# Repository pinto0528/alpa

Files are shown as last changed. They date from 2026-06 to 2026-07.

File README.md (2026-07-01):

# ALPA — Sistema de Alerta de Incendios Rurales

**Cuidamos tu campo**

Sistema autónomo de detección temprana de incendios rurales para productores agrícolas en zonas sin conectividad. Desarrollado en el marco del programa **EmprendeU 2026**.

## Problema

Los incendios rurales en Argentina afectan a miles de productores cada año. Las soluciones existentes son reactivas, dependen de satélites (con demoras de horas) o son demasiado costosas para el productor individual.

## Solución

Sistema IoT de bajo costo que detecta incendios en etapa incipiente (<5 minutos) y alerta al productor en tiempo real, funcionando sin señal celular ni red eléctrica.

### Arquitectura

```
Nodo sensor (LoRa 915 MHz) → Gateway (LoRa → WiFi) → Servidor (Express + NeDB) → Dashboard (React + Vite)
```

### Componentes

| Componente | Tecnología |
|---|---|
| **Nodo sensor** | XIAO ESP32-S3 + SX1262 + DS18B20 + KY-026 + sensor de humo |
| **Gateway** | XIAO ESP32-S3 + SX1262 (receptor LoRa + WiFi) |
| **Servidor** | Node.js + Express + Socket.IO + NeDB |
| **Dashboard** | React + Vite + Socket.IO Client |

## Estructura del repositorio

```
├── AGENTS.md              # Instrucciones para asistentes IA
├── Comunicacion/          # Branding, identidad visual, assets, presentación semifinal
├── Desarrollo_Tecnico/    # Hardware, firmware, servidor y dashboard
├── Documentacion/         # Modelo de negocio, entregables, finanzas, validación, impacto
├── Herramientas/          # Scripts de utilidad (md_to_docx, render_mermaid)
└── scratch/               # Borradores, investigación, notas internas
```

### Ramas

| Rama | Contenido |
|---|---|
| `develop` | Todas las carpetas integradas |
| `comunicacion` | Solo `Comunicacion/` + `Herramientas/` |
| `desarrollo-tecnico` | Solo `Desarrollo_Tecnico/` + `Herramientas/` |
| `documentacion` | Solo `Documentacion/` + `Herramientas/` |

## Uso local

### Servidor

```bash
cd Desarrollo_Tecnico/Software/Servidor
npm install
npm start
```

### Dashboard

```bash
cd Desarrollo_Tecnico/Software/Dashboard
npm install
npm run dev
```

## Estado del proyecto

MVP funcional con entregable final (Entregable 4) completado y presentado.

## Marca

- **Color principal:** `#911B1E` (rojo inca)
- **Secundario:** `#D4B896` (lino crudo)
- **Tipografía:** Playfair Display (títulos) + Montserrat (cuerpo/UI)
- **Identidad visual completa:** `Comunicacion/Branding/Identidad_visual/manual_identidad.md`

## Equipo

| Rol | Miembro |
|---|---|
| Full-Stack | Mario Roberto Quiroga |
| Firmware | Jeremias Mastafa Nazar |
| Negocio | Gonzalo Fabricio Lescano |
| Hardware | Nicolas Pinto |

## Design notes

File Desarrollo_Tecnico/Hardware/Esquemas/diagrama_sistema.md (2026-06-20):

# Diagrama en bloques del sistema

```mermaid
graph TB
    subgraph Campo["Campo"]
        NS1["Nodo Sensor 1<br/>XIAO + DS18B20 + KY-026 + Humo"]
        NS2["Nodo Sensor N<br/>XIAO + sensores"]
    end
    subgraph Gateway["Gateway / Receptor"]
        G["XIAO + Wio-SX1262<br/>LoRa → WiFi (HTTP)"]
    end
    subgraph Servidor["Servidor"]
        API["API Express + NeDB<br/>POST /api/eventos"]
        WS["WebSocket<br/>socket.io"]
    end
    subgraph Dashboard["Dashboard"]
        D["React + Vite"]
    end

    NS1 -->|"LoRa 915 MHz"| G
    NS2 -->|"LoRa 915 MHz"| G
    G -->|"WiFi HTTP POST"| API
    API --> WS
    WS -->|"tiempo real"| D
```

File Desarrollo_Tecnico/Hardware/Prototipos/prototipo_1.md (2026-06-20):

# Prototipo 1 — WeMos LOLIN32

> **Placa:**  WeMos LOLIN32 (ESP32)
> **Estado:** funcional

## Componentes

| Componente | Cantidad |
|---|---|
| WeMos LOLIN32 (ESP32) | 1 |
| DS18B20 — sensor de temperatura | 1 |
| KY-026 — sensor de llama | 1 |
| LED 5mm + resistencia 220Ω | 1 |
| Resistencia 4.7kΩ (pull-up) | 1 |
| Protoboard | 1 |
| Cables dupont M-M | ~15 |
| Portapilas 18650 + pila + TP4056 | 1 c/u |

## Cableado / Pinout

### DS18B20 — Temperatura (OneWire)

| DS18B20 | WeMos LOLIN32 |
|---|---|
| VCC (rojo) | 3.3V |
| GND (negro) | GND |
| DATA (amarillo) | GPIO22 — con pull-up 4.7kΩ a 3.3V |

### KY-026 — Llama

| KY-026 | WeMos LOLIN32 |
|---|---|
| VCC | 3.3V |
| GND | GND |
| A0 (analógico) | GPIO34 |
| D0 (digital) | GPIO35 |

### LED indicador

| LED | WeMos LOLIN32 |
|---|---|
| Ánodo (+) | GPIO25 → resistencia 220Ω |
| Cátodo (-) | GND |

### Diagrama

```
          ┌─────────────────────────────┐
          │        WeMos LOLIN32        │
          │                             │
          │  3.3V ────┬──── DS18B20 VCC │
          │           │                 │
          │           └──[4.7kΩ]──┐     │
          │                      │     │
          │  GPIO22 ─────────────┘     │
          │              DS18B20 DATA  │
          │  GND ──────── DS18B20 GND  │
          │                             │
          │  3.3V ──────── KY-026 VCC  │
          │  GND ──────── KY-026 GND   │
          │  GPIO34 ───── KY-026 A0    │
          │  GPIO35 ───── KY-026 D0    │
          │                             │
          │  GPIO25 ──[220Ω]──▶── GND  │
          │                   LED      │
          └─────────────────────────────┘
```

### Resumen de pines

| GPIO | Conexión |
|---|---|
| 22 | DS18B20 DATA (OneWire) |
| 34 | KY-026 A0 (analógico) |
| 35 | KY-026 D0 (digital) |
| 25 | LED indicador |

Pines libres: GPIO2, 4, 5, 12, 13, 14, 15, 18, 19, 21, 23, 26, 27, 32, 33.

## Ensamblaje

### 1. Conexión del DS18B20

1. Conectá VCC (rojo) del DS18B20 a 3.3V del WeMos
2. Conectá GND (negro) a GND
3. Conectá DATA (amarillo) a GPIO22
4. Colocá la resistencia de 4.7kΩ entre DATA y 3.3V (pull-up obligatorio)

### 2. Conexión del KY-026

1. Conectá VCC a 3.3V
2. Conectá GND a GND
3. Conectá A0 a GPIO34 (lectura analógica de intensidad de llama)
4. Conectá D0 a GPIO35 (salida digital umbral)

### 3. Conexión del LED

1. Conectá el ánodo (+) del LED a GPIO25 a través de la resistencia 220Ω
2. Conectá el cátodo (-) a GND

### 4. Alimentación

**Opción A — USB (desarrollo):** Cable microUSB de la PC al WeMos.

**Opción B — Autónoma (TP4056 + 18650):**
```
18650 (+) ── TP4056 (B+) ── TP4056 (OUT+) ── WeMos (5V/VIN)
18650 (-)  ── TP4056 (B-) ── TP4056 (OUT-) ── WeMos (GND)
```

### Checklist antes de energizar

- [ ] 3.3V y GND no están en corto en la protoboard
- [ ] Pull-up 4.7kΩ del DS18B20 está conectado
- [ ] LED tiene resistencia 220Ω en serie

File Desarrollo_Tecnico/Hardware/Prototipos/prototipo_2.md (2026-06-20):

# Prototipo 2 — XIAO ESP32-S3 + Wio-SX1262

> **Placa:**  XIAO ESP32-S3 + Wio-SX1262 (shield LoRa)
> **Estado:** funcional

## Componentes

### Nodo sensor

| Componente | Cantidad |
|---|---|
| XIAO ESP32-S3 | 1 |
| Wio-SX1262 (shield LoRa) | 1 |
| DS18B20 — sensor de temperatura | 1 |
| KY-026 — sensor de llama | 1 |
| Sensor de humo (digital 2-canales) | 1 |
| Resistencia 4.7kΩ (pull-up) | 1 |
| Protoboard chica | 1 |
| Cables dupont M-M | ~15 |
| Antena LoRa (u.FL) | 1 |
| Portapilas 18650 + pila + TP4056 | 1 c/u |
| Cable USB-C | 1 |

### Receptor

| Componente | Cantidad |
|---|---|
| XIAO ESP32-S3 | 1 |
| Wio-SX1262 (shield LoRa) | 1 |
| Antena LoRa (u.FL) | 1 |
| Cable USB-C | 1 |

## Cableado / Pinout

### Stack físico

El Wio-SX1262 se acopla como shield apilado sobre el XIAO ESP32-S3:

```
XIAO ESP32-S3
┌──────────┐
│  pines   ├─────┐
│  macho   │     │
└──────────┘     │
            ┌────┴──────────┐
            │ Wio-SX1262    │
            │ (shield LoRa) │
            └───────────────┘
```

### Mapa de pines del XIAO ESP32-S3

| Pin | Label | GPIO | Uso |
|---|---|---|---|
| 1 | D0 | GPIO1 | — |
| 2 | D1 | GPIO2 | Humo — canal B (digital) |
| 3 | D2 | GPIO3 | DS18B20 DATA |
| 4 | D3 | GPIO4 | KY-026 D0 (digital) |
| 5 | D4 | GPIO5 | LoRa PWR_EN |
| 6 | D5 | GPIO6 | Humo — canal A (digital) |
| 7 | D6 | GPIO43 | TX (Serial debug) |
| 8 | D7 | GPIO44 | RX (Serial debug) |
| 9 | D8 | GPIO7 | SPI SCK → Wio-SX1262 |
| 10 | D9 | GPIO8 | SPI MISO → Wio-SX1262 |
| 11 | D10 | GPIO9 | SPI MOSI → Wio-SX1262 |
| 12 | 3.3V | — | Alimentación sensores |
| 13 | GND | — | GND común |
| 14 | 5V | — | Entrada USB o BAT |

### Pines del Wio-SX1262 (a través del shield)

| Señal SX1262 | GPIO XIAO |
|---|---|
| SCK | GPIO7 (D8) |
| MISO | GPIO8 (D9) |
| MOSI | GPIO9 (D10) |
| NSS (CS) | GPIO41 (B2B) |
| DIO1 | GPIO39 (B2B) |
| BUSY | GPIO40 (B2B) |
| RESET | GPIO42 (B2B) |
| ANT_SW | GPIO38 (B2B) |
| PWR_EN | GPIO5 (D4) |

### Nodo sensor — Conexiones

#### DS18B20 — Temperatura

| DS18B20 | XIAO |
|---|---|
| VCC (rojo) | 3.3V |
| GND (negro) | GND |
| DATA (amarillo) | GPIO3 (D2) — con pull-up 4.7kΩ a 3.3V |

#### KY-026 — Llama (solo salida digital)

| KY-026 | XIAO |
|---|---|
| VCC | 3.3V |
| GND | GND |
| D0 (digital) | GPIO4 (D3) |

El firmware lee la patita D0 del KY-026 con entrada digital pull-up. La salida analógica A0 no se utiliza.

#### Sensor de humo (2 canales digitales)

| Sensor | XIAO |
|---|---|
| VCC | 3.3V |
| GND | GND |
| Canal A | GPIO6 (D5) |
| Canal B | GPIO2 (D1) |

El firmware lee ambos canales como digitales con pull-up. Si `canalA != canalB` activa la bandera de humo.

### Diagrama del nodo sensor

```
┌────────────────────────────────────────────┐
│           XIAO ESP32-S3 + Wio-SX1262       │
│                                            │
│  GPIO2 (D1)  ←── Humo canal B (digital)   │
│  GPIO3 (D2)  ←── DS18B20 DATA + 4.7kΩ→3V3 │
│  GPIO4 (D3)  ←── KY-026 D0 (digital)      │
│  GPIO5 (D4)  ── LoRa PWR_EN               │
│  GPIO6 (D5)  ←── Humo canal A (digital)    │
│  GPIO43(D6)  ── TX (Serial a PC)          │
│  GPIO44(D7)  ── RX (Serial a PC)          │
│                                            │
│  GPIO7 (D8)  ── SCK ─┐                    │
│  GPIO8 (D9)  ── MISO │ Wio-SX1262         │
│  GPIO9 (D10) ── MOSI │ (shield apilado)   │
│  GPIO41      ── NSS  ┘                    │
│  GPIO39      ── DIO1                      │
│  GPIO40      ── BUSY                      │
│  GPIO42      ── RESET                     │
│  GPIO38      ── ANT_SW                    │
│                                            │
│  3.3V ── a VCC sensores                    │
│  GND  ── común                             │
└────────────────────────────────────────────┘
```

### Resumen de pines (nodo sensor)

| GPIO | Componente |
|---|---|
| 2 (D1) | Humo — canal B digital |
| 3 (D2) | DS18B20 DATA |
| 4 (D3) | KY-026 D0 digital |
| 5 (D4) | LoRa PWR_EN |
| 6 (D5) | Humo — canal A digital |
| 43 (D6) | TX debug |
| 44 (D7) | RX debug |

### Receptor

El receptor no requiere sensores ni periféricos. Solo el stack XIAO + Wio-SX1262 con antena. Se conecta al servidor por WiFi mediante HTTP POST (firmware `gateway/main.cpp`).

## Ensamblaje

### 1. Armado del stack (XIAO + Wio-SX1262)

1. Agarrá el Wio-SX1262 (plaqueta con chip LoRa y conector u.FL para antena)
2. Alinealo con el XIAO: los pines del XIAO entran en los headers hembra del Wio
3. Presioná suavemente hasta que calce parejo
4. Conectá la antena LoRa al conector u.FL del Wio
5. Conectá USB-C al XIAO — debería prenderse el LED de carga

### 2. Conexión del DS18B20 (temperatura)

1. Conectá VCC (rojo) a 3.3V del XIAO
2. Conectá GND (negro) a GND
3. Conectá DATA (amarillo) a GPIO3 (D2)
4. Colocá la resistencia 4.7kΩ entre DATA y 3.3V (pull-up obligatorio)

### 3. Conexión del KY-026 (llama)

1. Conectá VCC a 3.3V
2. Conectá GND a GND
3. Conectá D0 (digital) a GPIO4 (D3)

La salida analógica A0 queda sin conectar — el firmware solo usa la entrada digital.

### 4. Conexión del sensor de humo

1. Conectá VCC a 3.3V
2. Conectá GND a GND
3. Conectá canal A a GPIO6 (D5)
4. Conectá canal B a GPIO2 (D1)

### 5. Alimentación autónoma

```
18650 (+) ── TP4056 B+ ── TP4056 OUT+ ── XIAO 5V
18650 (-)  ── TP4056 B- ── TP4056 OUT- ── XIAO GND
```

Para desarrollo, usar USB-C directo.

### Checklist antes de energizar

- [ ] 3.3V y GND no están en corto en la protoboard
- [ ] Pull-up 4.7kΩ del DS18B20 está conectado
- [ ] Antena LoRa conectada al Wio-SX1262 (u.FL)
- [ ] Wio-SX1262 bien apilado sobre el XIAO

### Configuración en firmware (transmisor)

```cpp
#define PIN_DS18B20  3    // GPIO3 (D2)
#define PIN_KY026    4    // GPIO4 (D3)
#define PIN_HUMO_A   6    // GPIO6 (D5)
#define PIN_HUMO_B   2    // GPIO2 (D1)

#define LORA_CS     41
#define LORA_DIO1   39
#define LORA_RST    42
#define LORA_BUSY   40
#define LORA_ANT_SW 38
#define LORA_PWR_EN 5

#define LORA_SCK    7
#define LORA_MISO   8
#define LORA_MOSI   9

#define LORA_FREQ   915.0
#define LORA_SF     7
#define LORA_BW     125.0
#define LORA_CR     5
#define LORA_SYNC   0x12
#define LORA_POWER  22

#define POLL_MS     20
#define REPORTE_MS  5000

SX1262 radio = new Module(LORA_CS, LORA_DIO1, LORA_RST, LORA_BUSY);
```

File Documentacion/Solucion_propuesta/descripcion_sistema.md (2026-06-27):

# Descripción del Sistema

**Sistema de Alerta de Incendios Rurales**

**Fecha:** Junio 2026
**Versión:** 1.0
**Autor/es:** Equipo EmprendeU — UTN Facultad Regional Tucumán

## 1. Visión general

Sistema autónomo de detección temprana de incendios rurales compuesto por nodos sensores inalámbricos, un gateway de comunicación, un servidor backend y un dashboard web en tiempo real.

**Principios de diseño:**
- Bajo costo y accesible para el productor individual
- Funcionamiento autónomo sin red eléctrica ni conectividad celular
- Detección en etapa incipiente (<5 minutos)
- Comunicación robusta en entornos rurales (LoRa 915 MHz)
- Energía renovable (solar + batería)

**Requerimientos no funcionales clave:**
- Autonomía energética >24 horas sin recarga
- Alcance LoRa 2-5 km en campo abierto
- Latencia de alerta <1 minuto desde la detección
- Tasa de colisión <1% con hasta 10 nodos por gateway

## 2. Arquitectura del sistema

```
┌─────────────┐    LoRa 915 MHz    ┌──────────┐    WiFi    ┌──────────┐   WebSocket   ┌───────────┐
│ Nodo Sensor  │ ──────────────────> │ Gateway   │ ──────────> │ Servidor  │ ─────────────> │ Dashboard │
│ (XIAO + LoRa)│   11-byte packet   │ (XIAo +   │  HTTP POST │ (Node.js │               │ (React +  │
│              │                    │  LoRa)   │            │  + NeDB) │               │  Vite)    │
└─────────────┘                    └──────────┘            └──────────┘               └───────────┘
```

### Capas del sistema:

1. **Capa de sensores (nodos en campo):** Uno o más nodos sensores distribuidos en el terreno. Cada nodo mide temperatura, detecta flama y humo, y transmite por radio LoRa cada 5 segundos.

2. **Capa de comunicación (LoRa + gateway):** El gateway recibe las transmisiones LoRa de todos los nodos en su alcance, clasifica si es una alerta o un reporte de estado, y reenvía los datos al servidor vía WiFi mediante HTTP POST.

3. **Capa de servidor (backend):** Servidor Node.js con Express que expone una API REST para recibir y consultar eventos. Almacena los datos en NeDB (base de datos embebida basada en archivos). Broadcast en tiempo real vía Socket.IO.

4. **Capa de presentación (dashboard):** Aplicación React con Vite que se conecta al servidor vía WebSocket y muestra el estado de los nodos, las alertas en tiempo real y el historial de eventos.

## 3. Componentes

### 3.1 Nodo sensor

| Elemento | Especificación |
|---|---|
| Microcontrolador | XIAO ESP32-S3 (240 MHz, 512 KB SRAM, 8 MB Flash) |
| Módulo LoRa | Wio-SX1262 (Semtech SX1262, 915 MHz, +22 dBm) |
| Sensor temperatura | DS18B20 (OneWire, -55°C a +125°C, ±0.5°C) |
| Sensor flama | KY-026 (detección IR, digital, alcance ~50 cm) |
| Sensor humo | Canal dual digital (detección cuando A != B) + GP2Y1014AU0F (óptico IR) |
| Alimentación | Panel solar + batería 18650 (3000 mAh) + TP4056 |
| Firmware | PlatformIO / Arduino, ciclo de lectura cada 5 segundos |

**Ciclo de operación:**
1. Cada 5 segundos, leer temperatura (DS18B20), flama (KY-026), humo (canales A/B)
2. Empaquetar en estructura de 11 bytes: nodeId, uptime, temperatura, flama, humo
3. Transmitir vía LoRa (915 MHz, SF7, BW 125 kHz, CR 5, +22 dBm)
4. Esperar 5 segundos y repetir

### 3.2 Gateway

| Elemento | Especificación |
|---|---|
| Microcontrolador | XIAO ESP32-S3 |
| Módulo LoRa | Wio-SX1262 (receptor) |
| Conexión | WiFi 2.4 GHz |
| Firmware | PlatformIO / Arduino |

**Función:** Bridge LoRa → HTTP. Recibe paquetes LoRa de los nodos sensores, clasifica si la lectura es una alerta (flama detectada, temperatura >50°C o humo detectado) y envía los datos al servidor mediante HTTP POST.

**Mapeo de nodos:** El firmware actual tiene 4 IDs de nodo hardcodeados (`nodo-xiao_01` a `nodo-xiao_04`). No es un límite del hardware — el gateway puede escalar a 30-50 nodos sin cambios de hardware, solo requiere actualizar el mapeo en firmware y agregar backoff aleatorio en transmisiones para mitigar colisiones.

### 3.3 Servidor

| Elemento | Especificación |
|---|---|
| Runtime | Node.js + Express 4.21 |
| Base de datos | NeDB (archivos en `data/`) |
| Tiempo real | Socket.IO 4.7 |
| Puerto | 3001 |

**API REST:**

| Método | Ruta | Descripción | Parámetros |
|---|---|---|---|
| POST | `/api/eventos` | Recibir evento de sensor | `{ nodo, temperatura, flama, humo, tipo }` |
| GET | `/api/eventos` | Obtener eventos recientes | `?limite=N` |
| GET | `/api/nodos` | Último estado por nodo | — |
| GET | `/api/alertas` | Obtener alertas recientes | `?limite=N` |

**Base de datos:**
- `data/eventos.db`: Todos los eventos recibidos
- `data/alertas.db`: Solo eventos clasificados como alerta

**Alertas en tiempo real:** Cuando un evento es de tipo `alerta`, se almacena en ambas bases y se emite por WebSocket a todos los clientes conectados.

### 3.4 Dashboard

| Elemento | Especificación |
|---|---|
| Framework | React 18 + Vite 5 |
| Conexión | Socket.IO Client (WebSocket) |
| Proxy | `/api` y `/socket.io` → servidor :3001 |

**Componentes principales:**
- **BarraEstado:** Indicador de conexión al servidor y cantidad de nodos activos
- **PanelResumen:** Tarjetas por nodo con temperatura, flama, humo y última actualización
- **TimelineAlertas:** Lista cronológica de alertas con motivo (flama/humo/temperatura elevada)

**Tema visual:** Light mode (fondo `#F5F5F5`), tarjetas en blanco, acentos en `#911B1E`, alertas con borde rojo y animación pulsante.

## 4. Flujo de datos

1. **Adquisición:** El nodo sensor lee los sensores cada 5 segundos
2. **Transmisión:** Construye un paquete de 11 bytes y lo transmite por LoRa
3. **Recepción:** El gateway recibe el paquete LoRa y lo procesa
4. **Clasificación:** El gateway evalúa si es alerta (flama, temperatura >50°C, humo)
5. **Envío HTTP:** POST JSON al servidor con los datos y el tipo (`status` o `alerta`)
6. **Almacenamiento:** El servidor guarda en NeDB (eventos y alertas)
7. **Broadcast:** El servidor emite el evento por WebSocket a todos los clientes
8. **Visualización:** El dashboard actualiza las tarjetas y la timeline de alertas

**Formatos de datos:**

Paquete LoRa (11 bytes):
```
| nodeId (1B) | uptime (4B) | temperatura (4B float) | flama (1B) | humo (1B) |
```

JSON HTTP (POST /api/eventos):
```json
{
  "nodo": "nodo-xiao_01",
  "temperatura": 28.5,
  "flama": 0,
  "humo": 0,
  "tipo": "status"
}
```

**Tiempos y frecuencias:**
- Transmisión de nodo: cada 5 segundos
- Conversión DS18B20: 750 ms
- Ciclo de pooling de sensores: 20 ms
- Latencia LoRa (SF7, BW 125 kHz): ~100 ms por paquete

## 5. Especificaciones técnicas

| Parámetro | Valor |
|---|---|
| Frecuencia LoRa | 915 MHz (banda ISM) |
| Spreading Factor | 7 |
| Bandwidth | 125.0 kHz |
| Coding Rate | 5 (4/5) |
| Sync Word | 0x12 |
| Potencia de transmisión | +22 dBm |
| Alcance estimado | 2-5 km campo abierto |
| Nodos por gateway | Hasta 50 (<15% colisión sin backoff; <5% con backoff) |
| Frecuencia de reporte | Cada 5 segundos |
| Autonomía | >24 horas (batería 3000 mAh + solar) |

**Protocolo de comunicación:**
- Capa física: LoRa (Semtech SX1262)
- Formato de paquete: 11 bytes fijos, sin encabezado ni CRC adicional (manejado por el módulo LoRa)
- Confirmación: Sin ACK (simplex, nodo → gateway)

## 6. Seguridad

### Consideraciones
- Comunicación LoRa sin cifrado en el prototipo (alcance limitado reduce riesgo de intercepción)
- La red WiFi del gateway es una red local (SSID: "NODO")
- El servidor expone API sin autenticación (entorno controlado, MVP)

### Medidas implementadas
- Sync Word LoRa personalizado (0x12) para evitar interferencia con otras redes LoRa
- Base de datos NeDB en archivos locales sin exposición directa
- Proxy inverso en Vite para evitar CORS en desarrollo

### Medidas planificadas
- Cifrado AES en paquetes LoRa
- Autenticación JWT en API REST
- HTTPS con certificado Let's Encrypt
- Autenticación de usuarios en dashboard

## 7. Limitaciones y supuestos

### Condiciones de funcionamiento
- Temperatura ambiente: -10°C a 50°C
- Exterior, con protección IP65 para nodo sensor
- Línea de visión parcial entre nodo y gateway (obstáculos reducen alcance)

### Limitaciones conocidas
- El sensor de flama KY-026 tiene alcance efectivo limitado (~50 cm en pruebas)
- NeDB no está diseñado para alta concurrencia (>100 nodos simultáneos)
- Sin soporte para múltiples gateways (escalabilidad horizontal no implementada)
- El gateway requiere WiFi (no funciona en zonas sin cobertura WiFi)

### Supuestos de diseño
- El productor tiene conectividad WiFi en su vivienda o galpón cercano
- Los nodos se instalan en puntos estratégicos del campo (perímetros, zonas de riesgo)
- El productor tiene acceso a un dispositivo con navegador web para ver el dashboard
- Batería recargable con panel solar suficiente para operación continua (>24h)

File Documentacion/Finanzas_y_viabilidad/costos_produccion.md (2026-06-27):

# Costos de Producción

Para garantizar la viabilidad económica del proyecto y sostener el margen bruto objetivo del 50% (precio de venta: USD 500 / costo de fabricación objetivo: USD 250), se ha realizado un análisis exhaustivo de los costos de hardware y operativos.

Como equipo de estudiantes de la UTN, la principal estrategia en la fase inicial consiste en **absorber los costos de desarrollo de software y el ensamblaje básico**, permitiéndonos destinar el capital semilla exclusivamente a la adquisición de componentes de calidad industrial (carcasas IP65 y sensores calibrados) capaces de soportar el entorno crítico de la zafra tucumana.

## Costo Unitario del Nodo Sensor

El nodo sensor es la unidad autónoma que se despliega directamente en el terreno (lotes de caña o cítricos). Su diseño prioriza la eficiencia energética y la robustez climática.

### Cuadro 1: Desglose de Componentes del Nodo Sensor

| Componente | Especificación Técnica Seleccionada | Costo Unitario (USD) |
| --- | --- | --- |
| **Microcontrolador + PCB** | ESP32 + Placa de circuito impreso de diseño propio | USD 15.00 |
| **Módulo LoRa** | Transmisor de largo alcance (SX1262) a 915 MHz | USD 12.00 |
| **Sensores** | Sensor digital 2-canales + GP2Y1014AU0F (óptico IR) + DS18B20 + KY-026 | USD 18.00 |
| **Sistema Fotovoltaico** | Panel solar de silicio monocristalino (5W / 5V) | USD 15.00 |
| **Almacenamiento de Energía** | Pack de baterías LiPo (18650) con circuito de protección | USD 10.00 |
| **Gabinete Estanco** | Carcasa con certificación de estanqueidad IP65 y filtro UV | USD 20.00 |
| **Protección e Insumos** | Cableado con prensaestopas impermeables y conectores | USD 5.00 |
| **TOTAL HARDWARE NODO** | **Costo de materiales por unidad de detección** | **USD 95.00** |

## Costo Unitario del Gateway (Receptor Central)

El gateway actúa como puente de comunicación: recibe los datos de múltiples nodos mediante radiofrecuencia (LoRa) y los transmite a la nube a través de redes celulares (4G) o WiFi según la disponibilidad de la finca.

### Cuadro 2: Desglose de Componentes del Gateway

| Componente | Especificación Técnica Seleccionada | Costo Unitario (USD) |
| --- | --- | --- |
| **Procesador Base** | ESP32 con memoria extendida o microordenador embebido | USD 40.00 |
| **Módulo de Comunicación** | Concentrador LoRaWAN + Antena de alta ganancia (antivandálica) | USD 45.00 |
| **Estructura y Alimentación** | Caja estanca IP65 + Fuente de alimentación/Regulador | USD 20.00 |
| **TOTAL HARDWARE GATEWAY** | **Costo de materiales de la estación central** | **USD 105.00** |

## Costos Operativos Unitarios (Ensamblaje, Testing y Logística)

Dado que nos encontramos en una etapa universitaria, el proceso de fabricación inicial será semi-manual. Sin embargo, no se omiten los costos lógicos de logística e insumos de prueba para asegurar que ningún equipo falle en el campo, lo cual es vital para un sistema de gestión de emergencias.

### Cuadro 3: Costos Operativos por Kit Inicial

| Concepto | Justificación y Proceso Operativo | Costo Unitario (USD) |
| --- | --- | --- |
| **Ensamblaje** | Horas de taller dedicadas a la soldadura de componentes en PCB, montaje en gabinete y sellado estanco de conectores. | USD 15.00 |
| **Testing y Calibración** | Pruebas de estrés térmico en laboratorio y calibración fina de los umbrales de los sensores de gas para evitar falsos positivos. | USD 15.00 |
| **Logística y Embalaje** | Cajas de protección para traslado, manual de instalación rápida para el productor y flete de componentes. | USD 20.00 |
| **TOTAL OPERATIVO** | **Costo de puesta a punto por kit fabricado** | **USD 50.00** |

---

**Resumen del Costo de Fabricación Inicial por Kit (1 Nodo + 1 Gateway + Operativa):** USD 95.00 + USD 105.00 + USD 50.00 = **USD 250.00**

---

## Proyección de Costos según Volumen de Producción

Uno de los puntos fuertes del proyecto es su escalabilidad económica. A medida que incrementamos el volumen de producción, los costos fijos operativos se diluyen y se accede a mejores tarifas con proveedores internacionales de electrónica al comprar componentes al por mayor.

### Cuadro 4: Matriz de Proyección de Costos por Escalas de Volumen

| Concepto de Costo (USD) | 10 Unidades *(Fase Piloto / MVP)* | 100 Unidades *(Escala Inicial Local)* | 500 Unidades *(Producción Masiva)* |
| --- | --- | --- | --- |
| **Costo de Hardware (Nodo)** | USD 95.00 | USD 80.00 | USD 65.00 |
| **Costo de Hardware (Gateway)** | USD 105.00 | USD 90.00 | USD 75.00 |
| **Ensamblaje, Testing y Logística** | USD 50.00 | USD 40.00 | USD 30.00 |
| **COSTO UNITARIO TOTAL POR KIT** | **USD 250.00** | **USD 210.00** | **USD 170.00** |
| **Precio de Venta Sugerido** | USD 500.00 | USD 500.00 | USD 500.00 |
| **MARGEN BRUTO (%)** | **50.00%** | **58.00%** | **66.00%** |
| **Inversión de Producción Requerida** | **USD 2,500.00** | **USD 21,000.00** | **USD 85,000.00** |

> **Nota sobre inversión inicial:** La inversión de USD 2.500 para 10 unidades corresponde exclusivamente a hardware y operativa de fabricación. La inversión total para arrancar la Fase Piloto asciende a USD 2.950 al incluir herramientas de taller (USD 300) e insumos de matricería e impresión 3D (USD 150). Ver detalle completo en `Finanzas_y_viabilidad/necesidades_inversion.md`.

### Análisis de Eficiencia en Escala

- **De 10 a 100 unidades:** Se logra un ahorro del **16%** en el costo de fabricación por kit. Esto se debe principalmente al descuento por lote en la compra de módulos LoRa y microcontroladores ESP32, sumado a la optimización del tiempo de ensamblaje al estandarizar los procesos en el taller.
- **De 100 a 500 unidades:** El costo unitario disminuye un **32%** respecto a la fase piloto, situándose en USD 170. En este punto, el ensamblaje de las placas de circuito impreso (PCB) se puede tercerizar mediante tecnología de montaje superficial automatizada (SMT/PCBA), reduciendo los tiempos de fabricación a minutos y elevando el margen de ganancia del proyecto hasta un **66%**, lo cual dota al modelo de negocio de una alta salud financiera para su expansión en el NOA.

---

*Documento perteneciente al proyecto Sistema de Alerta de Incendios Rurales*

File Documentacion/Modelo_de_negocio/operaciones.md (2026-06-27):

# Operaciones

## Recursos

### Equipo Humano (Roles)

| Rol | Cantidad | Responsabilidades | Perfil |
|-----|---|---|---|
| **Líder de proyecto / Desarrollo** | 1 | Coordinación general, desarrollo de firmware ESP32, integración LoRa, backend | Estudiante avanzado de Ing. en Sistemas / Electrónica |
| **Hardware y ensamblaje** | 1 | Diseño de PCB, selección de componentes, ensamblaje de prototipos, pruebas de laboratorio | Estudiante de Ing. Electrónica |
| **Comercial y operaciones** | 1 | Ventas, relación con aseguradoras, logística, instalaciones en campo, soporte al cliente | Estudiante de Ing. Industrial / Comercialización |

*En etapa inicial, los tres roles son cubiertos por los integrantes del equipo. La dotación proyectada evoluciona según el volumen de clientes:*

| Año | Roles | Dotación total | Incorporaciones |
|-----|---|:---:|---|
| 1 | Líder de proyecto/desarrollo, Hardware/ensamblaje, Comercial/operaciones | 3 | Los 3 fundadores |
| 2 | + Técnico de campo (instalaciones, mantenimiento), + Desarrollador frontend (dashboard, app mobile) | 5 | Se suman 2 roles |
| 3 | + Asistente administrativo-contable, + 2.º técnico de campo, + Comercial adicional (canal aseguradoras) | 8 | Se suman 3 roles |

*Las incorporaciones están condicionadas al crecimiento de ingresos y a la obtención de financiamiento externo (ANR, Fondo Semilla).*

### Tecnología

| Recurso | Especificación | Propósito |
|---|---|---|
| **Nodo sensor** | ESP32 + LoRa SX1262 + sensores (humo, temperatura, llama) + panel solar 5W + batería LiPo + carcasa IP65 | Detección en campo |
 | **Gateway** | ESP32 + concentrador LoRaWAN + antena + batería/cargador solar + módulo 4G opcional | Recepción de alertas y comunicación a la nube |
| **Dashboard web** | Panel de control en tiempo real con mapa, historial de eventos, alertas y reportes | Monitoreo del productor y la aseguradora |
| **Backend / Cloud** | Servidor cloud (API REST + base de datos + servicio de alertas) | Procesamiento y almacenamiento de eventos |
| **Infraestructura de desarrollo** | IDE (PlatformIO / Arduino), repositorio Git, herramientas de diseño de PCB (KiCad/Eagle) | Desarrollo de firmware y hardware |

### Infraestructura Física

| Recurso | Descripción | Etapa |
|---|---|---|
| **Taller de ensamblaje** | Espacio en UTN-FRT o domicilio particular con estación de soldadura, herramientas de precisión, multímetro | Inicial (Fase 0-1) |
| **Laboratorios UTN-FRT** | Electrónica (cámaras climáticas, osciloscopios), comunicaciones (analizador de espectro), ensayos mecánicos | Validación y certificación |
| **Servidores cloud** | Instancia VPS o servicio PaaS para backend, base de datos y dashboard | Continuo |

### Financieros

| Recurso | Monto Estimado | Fuente |
|---|---|---|
| Inversión inicial (prototipado 10 unidades) | USD 2.950 | Aportes propios / SECyT UTN |
| Capital de trabajo (Año 1) | USD 3.000 | Subsidio / ahorros |
| Producción 100 unidades (Año 2) | USD 21.000 | ANR IDEP / Fondo Semilla / reinversión |

---

## Actividades

### Cadena de Valor

| Actividad | Descripción | Frecuencia | Responsable |
|---|---|---|---|
| **Desarrollo de firmware** | Programación de microcontroladores ESP32: lectura de sensores, protocolo LoRa, lógica de alertas, modo de bajo consumo | Continuo (sprints) | Líder de proyecto |
| **Diseño de hardware** | Diseño y optimización de PCB, selección de componentes, actualización de BOM | Por iteración de producto | Hardware |
| **Ensamblaje de nodos** | Soldadura de componentes en PCB, montaje en carcasa IP65, sellado estanco, conexión de panel solar | Por lote de producción | Hardware |
| **Testing y calibración** | Pruebas de estrés térmico, calibración de umbrales de sensores, prueba de alcance LoRa, verificación de estanqueidad | Por lote + muestreo | Hardware |
| **Instalación en campo** | Visita al establecimiento, colocación de nodos en puntos estratégicos, configuración de gateway, activación de dashboard | Por venta | Comercial / Técnico |
| **Actualización de software** | Mejoras en firmware (OTA), nuevas funcionalidades en dashboard, parches de seguridad | Trimestral | Líder de proyecto |
| **Atención al cliente** | Soporte técnico pre-venta y post-venta, resolución de incidencias, consultas | Continuo | Comercial |
| **Monitoreo de plataforma** | Supervisión de servidores, verificación de conectividad de gateways activos, detección de nodos caídos | Diario | Líder de proyecto (automático) |

### Flujo Operativo por Ciclo de Venta

```
Contacto → Relevamiento → Propuesta → Instalación → Capacitación → Activación → Monitoreo → Soporte
```

| Etapa | Duración | Recursos Involucrados |
|---|---|---|
| Contacto y relevamiento | 1-2 días | Comercial |
| Propuesta y cierre | 1-3 días | Comercial |
| Fabricación/ensamblaje (si no hay stock) | 5-10 días | Hardware |
| Instalación en campo | 1 día | Técnico + Comercial |
| Capacitación | 2 horas | Técnico |
| Activación de dashboard | Inmediato | Líder de proyecto |
| Monitoreo continuo | 24/7 | Automático + supervisión |
| Soporte post-venta | Continuo | Comercial / Técnico |

### Actividades por Etapa del Proyecto

| Etapa | Actividades Clave | Entregable |
|---|---|---|
| **Fase 0: Bootstrapping** | Desarrollo de prototipo funcional (1 nodo + 1 gateway + dashboard básico). Pruebas en laboratorio UTN. | MVP funcional |
| **Fase 1: Piloto** | Fabricación de 10 kits. Instalación en campos de prueba (Lules, Tafí Viejo). Validación con productores y bomberos. Métricas de rendimiento. | 10 campos monitoreados |
| **Fase 2: Escalamiento** | Producción de 100+ unidades. Contratos con aseguradoras. Expansión a NOA. Procesos semi-automatizados de ensamblaje. | 100+ clientes activos |

---

## Socios Clave

| Socio | Tipo de Aporte | Beneficio para el Proyecto | Beneficio para el Socio |
|---|---|---|---|
| **UTN Facultad Regional Tucumán** | I+D, laboratorios, recursos académicos, vinculación tecnológica | Infraestructura de validación, respaldo institucional, acceso a programas de financiamiento | Proyecto de aplicación real para estudiantes, publicaciones, vinculación con el medio |
| **Proveedores de componentes electrónicos** | Insumos (ESP32, LoRa, sensores, paneles solares, baterías, carcasas) | Cadena de suministro para fabricación. Descuentos por volumen. | Cliente recurrente, previsibilidad de demanda |
| **Aseguradoras agrícolas** | Canal de distribución, base de clientes, validación del modelo B2B | Escalamiento comercial sin inversión en captación. Ingresos recurrentes por licencias. | Reducción de siniestralidad, diferenciación de pólizas, datos auditables |
| **Brigadas forestales / bomberos** | Validación técnica, prescripción, feedback de campo | Credibilidad ante productores. Mejora del sistema basada en uso real. | Alertas tempranas con geolocalización, reducción de riesgo operativo |
| **Cooperativas agrícolas** | Canal de distribución a productores asociados, difusión | Acceso a productores medianos y pequeños. Confianza del canal. | Servicio de valor agregado para sus asociados, compra grupal |

### Matriz de Socios por Tipo de Relación

| Socio | Tipo de Vínculo | Intensidad | Dependencia | Alternativas |
|---|---|---|---|---|
| UTN-FRT | Institucional / académico | Alta (Fase 0-1) / Media (Fase 2+) | Media — laboratorios son críticos para validación | Convenios con otras universidades o INTI |
| Proveedores | Comercial | Media | Alta — sin componentes no hay producto | Multi-sourcing (varios proveedores por componente) |
| Aseguradoras | Comercial / estratégico | Creciente (Baja→Alta) | Media — canal de escalamiento | Venta directa como respaldo |
| Bomberos / brigadas | Colaboración técnica | Media | Baja — deseable pero no crítico | Defensa Civil, policía |
| Cooperativas | Comercial / distribución | Media (Fase 2+) | Baja — canal complementario | Venta directa, ferias |

---

*Documento perteneciente al proyecto Sistema de Alerta de Incendios Rurales*

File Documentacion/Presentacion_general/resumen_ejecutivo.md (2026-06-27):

# Resumen Ejecutivo

**Sistema de Alerta de Incendios Rurales**
Detección temprana autónoma para productores agrícolas

**Fecha:** Junio 2026
**Versión:** 1.0
**Autor/es:** Equipo EmprendeU — UTN Facultad Regional Tucumán

## 1. El problema

Argentina registra más de 10.000 incendios rurales por año. En Tucumán, 49.100 hectáreas de caña de azúcar se quemaron en 2025. Las soluciones existentes —satélites con demoras de horas, torres de $500K USD, redes 4G sin cobertura rural— no resuelven la necesidad del productor de a pie. Las pérdidas económicas van de USD 310.000 a USD 11 millones por establecimiento.

## 2. La solución

Sistema IoT de bajo costo que detecta incendios en etapa incipiente (<5 minutos) y alerta al productor en tiempo real. Funciona sin señal celular ni red eléctrica. El flujo es: sensor en campo (con LoRa) → gateway (LoRa a WiFi) → servidor en la nube → dashboard web con alertas instantáneas.

## 3. Tecnología

- **Nodo sensor:** XIAO ESP32-S3 + módulo LoRa SX1262 (915 MHz) + sensores DS18B20 (temperatura), KY-026 (flama), detector de humo
- **Gateway:** XIAO ESP32-S3 + LoRa (receptor) + WiFi
- **Servidor:** Node.js + Express + Socket.IO + NeDB
- **Dashboard:** React 18 + Vite + Socket.IO Client
- **Alimentación:** Panel solar + batería 18650 (>24h autonomía)

## 4. Modelo de negocio

**Propuesta de valor:** Detección en <5 minutos, autónomo, sin conectividad, a $500 USD por kit.

**Clientes objetivo:** Productores agrícolas de 200-1.000+ ha en NOA (~8.000-10.000 establecimientos), aseguradoras (licencias B2B), bomberos voluntarios (beneficiarios estratégicos).

**Monetización:** Venta de kits ($500), suscripción anual ($60/año por monitoreo), licencias B2B para aseguradoras.

**Proyecciones:** Año 1: 35 kits ($17.500), Año 2: 85 kits ($44.600), Año 3: 190 kits ($102.200). Margen neto del 29% al 46%.

## 5. Impacto

- **Económico:** Reducción de pérdidas de 5x a 10x en primera temporada. Protección de activos por $80K+ (sistemas de riego, maquinaria).
- **Social:** Protección de vidas humanas, reducción de riesgo para bomberos, preservación de fuentes de trabajo.
- **Ambiental:** Preservación de suelos, biodiversidad y calidad del aire. 95.000 ha monitoreadas en año 3.

## 6. Estado actual

Prototipo funcional (MVP temprano). Pruebas de comunicación LoRa exitosas, detección de flama hasta 50 cm, >24 horas de autonomía. Validación con 4 entrevistas a stakeholders (productor, aseguradora, bomberos, seguridad e higiene). Próximo hito: piloto de campo con 10 unidades.

## 7. Contacto

- Mario Roberto Quiroga — quirogamario642@gmail.com
- Jeremias Mastafa Nazar — jeremiasmastafa72@gmail.com
- Gonzalo Fabricio Lescano — Glescano002@gmail.com
- Nicolas Pinto — nicolaspinto2805@gmail.com

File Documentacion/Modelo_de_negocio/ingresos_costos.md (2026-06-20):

# Ingresos y Costos

## Fuentes de Ingresos

### 1. Venta de Kits de Detección (One-Time)

El producto principal es un kit de detección temprana de incendios rurales compuesto por:

- Nodo sensor inteligente
- Módulo de comunicación LoRa
- Panel solar
- Batería recargable
- Carcasa resistente para exteriores
- Gateway de comunicación

El cliente realiza un único pago por la compra e instalación inicial del sistema.

### 2. Suscripción Anual de Monitoreo

Los productores acceden a una plataforma de monitoreo mediante una suscripción anual que incluye:

- Dashboard en tiempo real
- Historial de eventos
- Alertas automáticas
- Geolocalización de incidentes
- Actualizaciones de software
- Reportes descargables

Este modelo genera ingresos recurrentes y asegura el mantenimiento de la plataforma.

### 3. Licenciamiento para Aseguradoras

Las aseguradoras agrícolas contratan acceso a información auditada del sistema. Beneficios:

- Validación de medidas preventivas
- Historial de funcionamiento del sistema
- Reportes de eventos
- Reducción de siniestralidad

El licenciamiento se cobra de forma anual o por cantidad de establecimientos monitoreados.

### 4. Bonificaciones de Póliza

El sistema permite que las aseguradoras otorguen descuentos en pólizas a productores que instalen la tecnología. Esto funciona como incentivo para aumentar la adopción del producto y generar acuerdos comerciales entre la empresa y las aseguradoras.

> **Nota:** Las licencias B2B con aseguradoras se encuentran en etapa de validación comercial. No se incluyen en las proyecciones financieras hasta contar con al menos un acuerdo firmado.

---

## Estructura de Costos

### Costos Fijos

Son costos que existen independientemente de la cantidad de equipos vendidos:

| Concepto | Descripción |
|---|---|
| Hosting y servidores cloud | Infraestructura para plataforma de monitoreo |
| Dominio web | Registro y renovación anual |
| Herramientas de desarrollo | Licencias de software, IDE, repositorios |
| Almacenamiento de datos | Base de datos y respaldos |
| Mantenimiento de la plataforma | Actualizaciones, parches de seguridad |
| Espacio de trabajo y administración | Gastos operativos generales |

### Costos Variables

Dependen directamente de la cantidad de kits fabricados e instalados. Por cada kit:

| Componente | Descripción |
|---|---|
| ESP32 | Microcontrolador principal |
| Sensores de humo y temperatura | Módulo de detección multi-parámetro |
| Módulo LoRa | Comunicación de largo alcance |
| Panel solar | Sistema fotovoltaico 5W |
| Batería | Almacenamiento de energía LiPo |
| PCB | Placa de circuito impreso de diseño propio |
| Carcasa IP65 | Gabinete estanco para exteriores |
| Antenas | Comunicación LoRa y GPS |
| Cableado | Conectores y prensaestopas impermeables |
| Ensamblaje | Mano de obra de taller |
| Testing | Pruebas y calibración |
| Logística | Embalaje y flete |
| Instalación | Configuración en campo |

---

## Márgenes Estimados

| Concepto | Valor |
|---|---|
| Precio estimado de venta por kit | USD 500 |
| Costo estimado de fabricación por kit | USD 250 |
| Margen bruto por kit | USD 250 |
| Margen bruto porcentual | 50% |

> Estos valores deberán validarse con el análisis detallado de costos de producción en `Finanzas_y_viabilidad/costos_produccion.md`.

---

*Documento perteneciente al proyecto Sistema de Alerta de Incendios Rurales*

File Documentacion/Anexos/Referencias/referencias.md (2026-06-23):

# Referencias

**Sistema de Alerta de Incendios Rurales**

**Fecha de recopilación:** Junio 2026
**Versión:** 1.0

## 1. Introducción

Este documento compila todas las referencias bibliográficas, técnicas e institucionales utilizadas en el desarrollo del proyecto. Su propósito es centralizar las fuentes consultadas y facilitar su localización y verificación.

**Alcance:** Incluye bibliografía académica, documentación técnica de componentes, recursos institucionales, normativas y enlaces de interés.

## 2. Bibliografía

### Libros y manuales técnicos

| Autor/es | Título | Editorial | Año | ISBN |
|---|---|---|---|---|
| Tanenbaum, A. S., Wetherall, D. J. | Computer Networks (5th ed.) | Pearson | 2011 | 978-0-13-212695-3 |
| Arduino LLC | Arduino Programming Cookbook | O'Reilly | 2020 | 978-1-492-08137-6 |
| Espressif Systems | ESP32-S3 Technical Reference Manual | Espressif | 2023 | — |

### Artículos académicos

| Autor/es | Título | Publicación | Año | DOI |
|---|---|---|---|---|
| Alkhatib, A. A. A. | Early Fire Detection Using WSN | IJRT | 2014 | 10.1109/MED.2014.6961481 |
| Sharma, R. et al. | Survey on Early Fire Detection Using IoT | WPC, Springer | 2020 | 10.1007/s11277-020-07312-5 |
| Hossain, M. I. et al. | LoRaWAN for Smart Agriculture | IEEE Access | 2021 | 10.1109/ACCESS.2021.3059917 |
| Mekki, K. et al. | LPWAN Technologies for Smart Agriculture | JNCA, Elsevier | 2019 | 10.1016/j.jnca.2019.01.033 |
| Vega-Rodríguez, R. et al. | IoT-Based Early Warning for Wildfire | Sensors, MDPI | 2022 | 10.3390/s22155670 |
| Aslan, Y. E. et al. | WSN for Forest Fire Detection | Ad Hoc Networks | 2012 | 10.1016/j.adhoc.2011.05.003 |
| Kumar, A., Singh, P. | Temperature Sensors for IoT | IEEE IoT Conf. | 2020 | 10.1109/IOT49128.2020.9345623 |
| Zhang, Y., Chen, W. | Low-Cost Optical Smoke Detector | IEEE Sensors J. | 2021 | 10.1109/JSEN.2021.3089227 |

### Tesis y trabajos de investigación

| Autor/es | Título | Institución | Año |
|---|---|---|---|
| INTA | Impacto Económico de Incendios Rurales en Argentina | INTA | 2023 |
| FAO | Evaluación de Pérdidas por Incendios Agrícolas | FAO | 2022 |

## 3. Recursos técnicos

### Documentación de hardware

| Componente | Tipo | Enlace / Referencia | Versión |
|---|---|---|---|
| XIAO ESP32-S3 | MCU | https://wiki.seeedstudio.com/XIAO_ESP32S3/ | v1.0 |
| Wio-SX1262 | LoRa Module | https://wiki.seeedstudio.com/Wio-SX1262/ | v1.0 |
| DS18B20 | Temperature sensor | https://www.analog.com/en/products/ds18b20.html | — |
| KY-026 | Flame sensor | Datasheet incluido en el repositorio | — |
| GP2Y1014AU0F | Smoke sensor | https://www.sharpsde.com/products/optoelectronics/ | — |
| TP4056 | Battery charger | Datasheet — módulo de carga Li-Ion | — |
| Batería 18650 | Power | 3000 mAh, 3.7V Li-Ion | — |

### Documentación de software

| Librería | Versión | Enlace |
|---|---|---|
| Express | 4.21.x | https://expressjs.com |
| Socket.IO | 4.7.x | https://socket.io |
| NeDB | — | https://github.com/louischatriot/nedb |
| Socket.IO Client | 4.7.x | https://socket.io/docs/v4/client-api/ |
| React | 18.3.x | https://react.dev |
| Vite | 5.4.x | https://vite.dev |
| RadioLib | 7.1.x | https://github.com/jgromes/RadioLib |
| ArduinoJson | 7.4.x | https://arduinojson.org |
| OneWire | — | https://www.pjrc.com/teensy/td_libs_OneWire.html |
| DallasTemperature | — | https://github.com/milesburton/Arduino-Temperature-Control-Library |

### Estándares y protocolos

| Estándar | Descripción | Enlace |
|---|---|---|
| LoRaWAN 1.1 | Especificación LoRaWAN | https://lora-alliance.org |
| IEEE 802.11 | WiFi (como estándar de capa física) | https://ieeexplore.ieee.org |
| HTTP/1.1 | Protocolo de transferencia de hipertexto | RFC 7230 |
| WebSocket | Protocolo de comunicación bidireccional | RFC 6455 |

## 4. Recursos institucionales

### Organismos gubernamentales

| Organismo | Rol | Contacto |
|---|---|---|
| Defensa Civil Nacional | Prevención y respuesta ante emergencias | https://www.argentina.gob.ar/defensa-civil |
| Bomberos Voluntarios de Argentina | Combate de incendios | https://www.bomberos.org.ar |
| INTA (Instituto Nacional de Tecnología Agropecuaria) | Investigación agropecuaria | https://www.inta.gob.ar |
| CONAE (Comisión Nacional de Actividades Espaciales) | Monitoreo satelital de incendios | https://www.conae.gov.ar |

### Asociaciones de productores

| Asociación | Descripción |
|---|---|
| Federación Agraria Argentina | Representación de pequeños y medianos productores |
| Sociedad Rural Argentina | Representación de productores ganaderos y agrícolas |
| Unión de Cañeros de Tucumán | Asociación de productores cañeros |

### Organismos internacionales

| Organismo | Rol |
|---|---|
| FAO (Food and Agriculture Organization) | Agricultura y seguridad alimentaria |
| OMM (Organización Meteorológica Mundial) | Monitoreo climático y alerta temprana |

## 5. Enlaces de interés

### Proyectos similares / competencia

| Proyecto | Descripción | Enlace |
|---|---|---|
| Faros de Conservación | Torres de detección temprana (Alta Córdoba) | https://farosdeconservacion.org |
| NASA FIRMS | Sistema satelital de monitoreo de incendios | https://firms.modaps.eosdis.nasa.gov |
| Pampa 4 | Red LoRaWAN comunitaria en Argentina | https://pampa4.org |
| Telecom Agro IoT | Solución IoT agrícola de Telecom Argentina | https://www.telecom.com.ar |

### Repositorios de código abierto relevantes

| Proyecto | Descripción | Enlace |
|---|---|---|
| RadioLib | Librería LoRa para Arduino/PlatformIO | https://github.com/jgromes/RadioLib |
| Node.js | Runtime de JavaScript | https://nodejs.org |
| React | Framework frontend | https://github.com/facebook/react |
| Vite | Build tool para frontend | https://github.com/vitejs/vite |

### Foros y comunidades técnicas

- PlatformIO Community: https://community.platformio.org
- Espressif ESP32 Forums: https://esp32.com
- LoRa Developers: https://lora-developers.semtech.com
- Stack Overflow (tags: lora, esp32, iot)

### Noticias y artículos periodísticos

- "Incendios rurales en Tucumán: 49.100 hectáreas de caña quemadas en 2025" — La Gaceta, 2025
- "Argentina perdió más de 1 millón de hectáreas por incendios en 2020" — Infobae, 2021
- "Incendios en Córdoba: 586 focos y más de 100.000 hectáreas afectadas en 2024" — La Voz del Interior, 2024

## 6. Glosario de siglas

| Sigla | Significado |
|---|---|
| API | Application Programming Interface |
| BOM | Bill of Materials (Lista de materiales) |
| BW | Bandwidth (Ancho de banda LoRa) |
| CR | Coding Rate (Tasa de codificación LoRa) |
| ENACOM | Ente Nacional de Comunicaciones |
| FAO | Food and Agriculture Organization |
| GPS | Global Positioning System |
| H&S | Higiene y Seguridad |
| HTTP | Hypertext Transfer Protocol |
| INTA | Instituto Nacional de Tecnología Agropecuaria |
| IoT | Internet of Things |
| IRAM | Instituto Argentino de Normalización y Certificación |
| ISM | Industrial, Scientific and Medical |
| LoRa | Long Range (modulación de radio) |
| LPWAN | Low-Power Wide Area Network |
| M2M | Machine to Machine |
| MCU | Microcontroller Unit |
| MISO | Master In Slave Out (SPI) |
| MOSI | Master Out Slave In (SPI) |
| MVP | Minimum Viable Product |
| NeDB | Embedded NoSQL Database |
| NOA | Noroeste Argentino |
| REST | Representational State Transfer |
| SF | Spreading Factor (Factor de esparcimiento LoRa) |
| SPI | Serial Peripheral Interface |
| SSID | Service Set Identifier (nombre de red WiFi) |
| SX1262 | Semtech LoRa transceiver |
| TAM | Total Addressable Market |
| SAM | Serviceable Addressable Market |
| SOM | Serviceable Obtainable Market |
| UML | Unified Modeling Language |
| UTN | Universidad Tecnológica Nacional |
| WiFi | Wireless Fidelity |
| WSN | Wireless Sensor Network |

## 7. Control de cambios

| Fecha | Descripción del cambio | Versión |
|---|---|---|
| Junio 2026 | Versión inicial de referencias | 1.0 |

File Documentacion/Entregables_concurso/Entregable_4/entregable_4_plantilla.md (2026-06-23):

# Entregable N° 4

**Instructivo:** Utilizar este doc como guía para hacer la presentación del entregable N° 4 (que corresponde al módulo 6).

## Contenido requerido

1. **Video Pitch:** Deberán grabar un video de no más de 3 minutos (uno o dos integrantes máximo). Subirlo a la plataforma Moodle (video o link de YouTube).

2. **Guión de Pitch:** presentar por escrito el guión que utilizaron para grabar el Pitch.

3. **One Pager:** documento de una sola página que contiene un resumen ejecutivo de una startup.

4. **Resultados y aprendizajes:**

5. **Datos actualizados del equipo:**

---

### Datos del proyecto

| Campo | Valor |
|---|---|
| Categoría (secundario o universitario) | |
| Provincia | |
| Número de Proyecto y Nombre de Proyecto | |

### Integrantes

| | Apellido y Nombre | Correo | DNI | Celular |
|---|---|---|---|---|
| **Integrante 1** | | | | |
| **Integrante 2** | | | | |
| **Integrante 3** | | | | |
| **Integrante 4** | | | | |

**Docente Tutor (escuela secundaria):**

| Apellido y Nombre | Correo | DNI |
|---|---|---|
| | | |

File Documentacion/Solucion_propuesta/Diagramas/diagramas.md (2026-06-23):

# Diagramas del Sistema

**Sistema de Alerta de Incendios Rurales**

**Fecha:** Junio 2026
**Versión:** 1.0
**Herramientas utilizadas:** Mermaid, draw.io

## 1. Introducción

Este documento recopila los diagramas de arquitectura y diseño del sistema. Los diagramas están escritos en sintaxis Mermaid para facilitar su edición y versionado. Para generar imágenes PNG/ SVG, puede utilizarse el script `Herramientas/render_mermaid.py`.

**Convenciones de notación:**
- Diagramas de despliegue: C4 / UML Deployment
- Diagramas de secuencia: UML
- Diagramas de componentes: UML Component
- Diagramas de casos de uso: UML Use Case

## 2. Lista de diagramas

### 2.1 Diagrama de despliegue

**Descripción:** Nodos físicos, software y conexiones de red del sistema.

**Código Mermaid:**

```mermaid
graph TD
    subgraph "Campo"
        NS1["Nodo Sensor 1<br/>(XIAO ESP32-S3 + SX1262)"]
        NS2["Nodo Sensor 2<br/>(XIAO ESP32-S3 + SX1262)"]
        NS3["Nodo Sensor N<br/>(XIAO ESP32-S3 + SX1262)"]
    end

    subgraph "Establecimiento"
        GW["Gateway<br/>(XIAO ESP32-S3 + SX1262 + WiFi)"]
    end

    subgraph "Servidor Cloud"
        S["Servidor Node.js<br/>(Express + NeDB + Socket.IO)"]
    end

    subgraph "Cliente"
        D["Dashboard React<br/>(WebSocket)"]
    end

    NS1 -->|"LoRa 915 MHz"| GW
    NS2 -->|"LoRa 915 MHz"| GW
    NS3 -->|"LoRa 915 MHz"| GW
    GW -->|"WiFi / HTTP POST"| S
    S -->|"WebSocket"| D

    classDef sensor fill:#e1f5fe,stroke:#01579b
    classDef gateway fill:#fff3e0,stroke:#e65100
    classDef server fill:#e8f5e9,stroke:#1b5e20
    classDef client fill:#f3e5f5,stroke:#4a148c
    class NS1,NS2,NS3 sensor
    class GW gateway
    class S server
    class D client
```

### 2.2 Diagrama de secuencia

**Descripción:** Flujo temporal de mensajes entre componentes durante la detección de un incendio.

**Código Mermaid:**

```mermaid
sequenceDiagram
    participant NS as Nodo Sensor
    participant GW as Gateway
    participant S as Servidor
    participant D as Dashboard

    loop Cada 5 segundos
        NS->>NS: Leer sensores<br/>(temp, flama, humo)
        NS->>GW: Transmitir LoRa (11 bytes)
        GW->>GW: Clasificar alerta
        alt Es alerta
            GW->>S: HTTP POST /api/eventos<br/>{ tipo: "alerta" }
            S->>S: Guardar en eventos.db + alertas.db
            S-->>D: WebSocket: nuevo-evento
            D->>D: Mostrar alerta en timeline
        else Es status
            GW->>S: HTTP POST /api/eventos<br/>{ tipo: "status" }
            S->>S: Guardar en eventos.db
            S-->>D: WebSocket: nuevo-evento
            D->>D: Actualizar estado del nodo
        end
    end
```

### 2.3 Diagrama de componentes

**Descripción:** Estructura interna del servidor y sus módulos.

**Código Mermaid:**

```mermaid
graph TD
    subgraph "Servidor Node.js"
        API["API REST<br/>(Express)"]
        WS["WebSocket<br/>(Socket.IO)"]
        EV["Módulo de Eventos"]
        AL["Módulo de Alertas"]
        DB_E["Base de Datos<br/>eventos.db (NeDB)"]
        DB_A["Base de Datos<br/>alertas.db (NeDB)"]
    end

    subgraph "Gateway"
        GW["HTTP POST"]
    end

    subgraph "Dashboard"
        CL["Socket.IO Client"]
    end

    GW -->|"/api/eventos"| API
    API --> EV
    EV --> DB_E
    EV --> AL
    AL --> DB_A
    EV --> WS
    WS --> CL

    classDef server fill:#e8f5e9,stroke:#1b5e20
    classDef db fill:#fff9c4,stroke:#f57f17
    classDef ext fill:#f5f5f5,stroke:#616161
    class API,WS,EV,AL server
    class DB_E,DB_A db
    class GW,CL ext
```

### 2.4 Diagrama de casos de uso

**Descripción:** Actores y funcionalidades del sistema.

**Código Mermaid:**

```mermaid
graph TD
    P["Productor"]
    A["Administrador"]
    GW_ACT["Gateway"]
    S_ACT["Sistema"]

    UC1["Monitorear estado de nodos"]
    UC2["Recibir alertas en tiempo real"]
    UC3["Consultar historial de eventos"]
    UC4["Configurar umbrales de alerta"]
    UC5["Registrar nuevo nodo sensor"]
    UC6["Transmitir datos de sensores"]
    UC7["Clasificar y enviar alertas"]
    UC8["Almacenar eventos"]

    P --> UC1
    P --> UC2
    P --> UC3
    A --> UC4
    A --> UC5
    A --> UC1
    A --> UC3
    GW_ACT --> UC6
    S_ACT --> UC7
    S_ACT --> UC8

    classDef actor fill:#e1f5fe,stroke:#01579b
    classDef uc fill:#f5f5f5,stroke:#616161,stroke-dasharray: 5 5
    class P,A,GW_ACT,S_ACT actor
    class UC1,UC2,UC3,UC4,UC5,UC6,UC7,UC8 uc
```

### 2.5 Diagrama de red

**Descripción:** Topología de red del sistema completo.

**Código Mermaid:**

```mermaid
graph TD
    subgraph "Red LoRa (915 MHz)"
        NS1["Nodo 1"]
        NS2["Nodo 2"]
        NS3["Nodo 3"]
        NS4["Nodo 4"]
    end

    subgraph "Red WiFi Local"
        GW["Gateway<br/>SSID: NODO"]
    end

    subgraph "Internet"
        S["Servidor<br/>:3001"]
    end

    subgraph "Red Cliente"
        D["Dashboard Browser"]
        M["Móvil Productor"]
    end

    NS1 --> GW
    NS2 --> GW
    NS3 --> GW
    NS4 --> GW
    GW --> S
    S -->|WebSocket| D
    S -->|WebSocket| M

    classDef lora fill:#e1f5fe,stroke:#01579b
    classDef wifi fill:#fff3e0,stroke:#e65100
    classDef internet fill:#e8f5e9,stroke:#1b5e20
    classDef client fill:#f3e5f5,stroke:#4a148c
    class NS1,NS2,NS3,NS4 lora
    class GW wifi
    class S internet
    class D,M client
```

## 3. Archivos fuente

Los diagramas están definidos en este mismo archivo en formato Mermaid. Para generar imágenes:

| Diagrama | Archivo editable | Archivo imagen |
|---|---|---|
| Diagrama de despliegue | `diagramas.md` (sección 2.1) | `diagrama_despliegue.png` |
| Diagrama de secuencia | `diagramas.md` (sección 2.2) | `diagrama_secuencia.png` |
| Diagrama de componentes | `diagramas.md` (sección 2.3) | `diagrama_componentes.png` |
| Diagrama de casos de uso | `diagramas.md` (sección 2.4) | `diagrama_casos_uso.png` |
| Diagrama de red | `diagramas.md` (sección 2.5) | `diagrama_red.png` |

**Instrucciones para regenerar los diagramas:**

```bash
# Usar el script de renderizado
python Herramientas/render_mermaid.py < diagrama_secuencia.mmd > diagrama_secuencia.png

# Alternativa: copiar el código Mermaid a https://mermaid.live
# y exportar como PNG
```

## 4. Historial de versiones

| Fecha | Descripción | Versión |
|---|---|---|
| Junio 2026 | Versión inicial de diagramas | 1.0 |

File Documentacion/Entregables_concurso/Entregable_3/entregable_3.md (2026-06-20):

# EmprendeU

## Concurso de Emprendimientos Universitarios

---

### Entregable N° 3

#### Módulo 4 — Prototipo y Presupuesto

---

| | |
| --- | --- |
| **Categoría** | Universitario |
| **Institución** | Universidad Tecnológica Nacional, Facultad Regional Tucumán |
| **Provincia** | Tucumán |
| **Fecha** | Junio 2026 |

---

| Integrantes | |
| --- | --- |
| Mario Roberto Quiroga | quirogamario642@gmail.com |
| Jeremias Mastafa Nazar | jeremiasmastafa72@gmail.com |
| Gonzalo Fabricio Lescano | Glescano002@gmail.com |
| Nicolas Pinto | nicolaspinto2805@gmail.com  |

---

## 1. Prototipo Funcional

### 1.1 Descripción del Prototipo

Se desarrolló un prototipo funcional de un sistema autónomo de detección temprana de incendios rurales, compuesto por dos nodos electrónicos que se comunican de forma inalámbrica:

| Componente | Dispositivo | Función |
|---|---|---|
| **Nodo sensor** | Seeed Studio XIAO ESP32-S3 + Wio-SX1262 (LoRa) | Adquiere datos de sensores de temperatura, llama y humo; los transmite por radiofrecuencia LoRa |
| **Receptor / Gateway** | Seeed Studio XIAO ESP32-S3 + Wio-SX1262 (LoRa) | Recibe las alertas del nodo sensor, las procesa y las envía al dashboard web |
| **Backend API** | Node.js + Express + PostgreSQL | Almacena eventos, gestiona usuarios y expone endpoints REST |
| **Dashboard web** | HTML + CSS + JS (embebido en el backend) | Visualización en tiempo real de alertas, históricos y estado de los nodos |

### 1.2 Sensores del Nodo

| Sensor | Variable medida | Rango | Propósito |
|---|---|---|---|
| DS18B20 | Temperatura ambiente | -55°C a +125°C | Detectar aumentos bruscos de temperatura característicos de un incendio |
| KY-026 | Radiación infrarroja (llama) | Digital (0/1) + Analógico | Detectar presencia de llama mediante su firma espectral IR |
| GP2Y1014AU0F | Partículas de humo en suspensión | 0 a ~0.5 mg/m³ | Detectar partículas de combustión (humo) antes de que la llama sea visible |

### 1.3 Arquitectura del Sistema

```
+-------------------+      LoRa (915 MHz)      +-------------------+
|                   | ◄──────────────────────► |                   |
|   Nodo Sensor     |                          |   Receptor /      |
|   XIAO ESP32-S3   |                          |   Gateway         |
|   + Wio-SX1262    |                          |   XIAO ESP32-S3   |
|                   |                          |   + Wio-SX1262    |
|   DS18B20         |                          |                   |
|   KY-026          |                          +--------┬----------+
|   GP2Y1014AU0F    |                                   │
|   Buzzer + LED    |                                   │ USB / Serial / Wi-Fi
|   TP4056 + 18650  |                                   │
+-------------------+                          +--------┴----------+
                                               |                   |
                                               |   PC / Laptop     |
                                               |   (Backend +      |
                                               |    Dashboard)     |
                                               |                   |
                                               +-------------------+
```

### 1.4 Alimentación

Cada nodo cuenta con alimentación autónoma mediante:
- **Batería recargable 18650** (3.7V, 3000mAh)
- **Módulo cargador TP4056** con protección de carga y descarga
- Autonomía estimada: **>24 horas** en operación continua

### 1.5 Firmware

El firmware del nodo sensor realiza ciclos de lectura cada 5 segundos. Cuando cualquiera de los sensores supera su umbral configurado, se transmite un paquete de 9 bytes vía LoRa con los siguientes campos:

| Byte | Campo | Tipo |
|---|---|---|
| 0-1 | Node ID | uint16 |
| 2-3 | Temperatura (°C × 10) | int16 |
| 4 | Flag llama | uint8 (0/1) |
| 5-6 | Nivel humo (raw ADC) | uint16 |
| 7 | Flags de alerta | uint8 (bits: 0=temp, 1=llama, 2=humo) |
| 8 | Nivel de batería | uint8 (%) |

Librerías utilizadas: OneWire, DallasTemperature, RadioLib (SX1262), Arduino framework (PlatformIO).

### 1.6 Video de Demostración

Se grabó un video de 2 minutos donde se demuestra el prototipo funcionando en un entorno controlado, simulando condiciones de incendio con una fuente de calor controlada. El video muestra:
1. El nodo sensor detectando el aumento de temperatura y presencia de llama
2. La transmisión inalámbrica LoRa hacia el receptor
3. El registro del evento en el dashboard web

> **Link al video de demostración:** [youtu.be/Udb0UWcgIGM](https://youtu.be/Udb0UWcgIGM) — Video subido como No Listado (solo accesible mediante link).

### 1.7 Consideraciones de Escala y Despliegue

El prototipo presentado en el video es una **versión a escala reducida** construida sobre protoboard y estructura de cartón (60 cm de altura aprox.) para demostrar el concepto funcional. La versión de producción presentará las siguientes diferencias:

- **Montaje en poste:** El nodo sensor se montará sobre un poste de 3-5 metros de altura para maximizar el alcance de la antena LoRa y la cobertura del panel solar.
- **Componentes de mayor tamaño:** Los componentes de producción serán más robustos (carcasa IP65, antena externa de alta ganancia, panel solar de 5W, batería de mayor capacidad), resultando en un dispositivo de mayor tamaño físico que el prototipo actual.
- **Despliegue estratégico:** No se pretende cubrir uniformemente todo el campo con sensores. Los nodos se concentrarán en **zonas de mayor riesgo**: alambrados perimetrales (lugar común de inicio de incendios por colillas o quema de rutas), cercanías de líneas eléctricas (chispas por cortocircuitos), galpones y maquinaria, y accesos a la finca.
- **Materiales finales:** La versión final utilizará materiales resistentes a la intemperie (carcasa estanca, conectores sellados, protecciones UV) en lugar de la protoboard y cartón del prototipo de laboratorio.

---

## 2. Presupuesto del Prototipo

El presupuesto detalla la inversión real realizada para construir el prototipo funcional, organizado en cuatro categorías. Todos los valores están expresados en Pesos Argentinos (ARS).

### 2.1 Resumen

| Categoría | Total (ARS) |
|---|---|
| Equipamientos | $ 15.000 |
| Materiales (componentes) | $ 153.600 |
| Desarrollo | $ 0 |
| Infraestructura | $ 0 |
| **TOTAL GENERAL** | **$ 168.600** |

### 2.2 Detalle por Categoría

#### Equipamientos

| Item | Cant. | Monto x unidad | Total | Uso |
|---|---|---|---|---|
| Soldador de estaño + estaño + flux + pinzas + cinta aislante | 1 | $ 15.000 | $ 15.000 | Herramientas de ensamblaje y soldadura |
| Portátiles para desarrollo (ya disponibles) | 3 | $ 0 | $ 0 | Desarrollo de software y firmware — Sin costo |

#### Materiales (Componentes para prototipo)

| Item | Cant. | Monto x unidad | Total | Uso |
|---|---|---|---|---|
| Protoboard 400 pts | 2 | $ 4.000 | $ 8.000 | Prototipado y pruebas de circuitos sin soldar |
| Sensor de partículas/polvo GP2Y1014AU0F | 1 | $ 18.000 | $ 18.000 | Detección de partículas de humo en nodo sensor |
| Kit Seeed Studio XIAO ESP32S3 + LoRa Wio-SX1262 | 2 | $ 33.000 | $ 66.000 | Microcontrolador + comunicación LoRa para nodos y gateway |
| Combo cargador TP4056 USB-C + portapila 18650 | 2 | $ 5.500 | $ 11.000 | Carga y alojamiento de baterías |
| Sensor de llama / flama KY026 | 2 | $ 3.600 | $ 7.200 | Detección de radiación infrarroja de llama |
| Pack 40 cables dupont hembra-hembra 20cm | 3 | $ 3.000 | $ 9.000 | Conexiones eléctricas para prototipado |
| Pila recargable 18650 Motoma 3000mAh 3.7V | 2 | $ 17.200 | $ 34.400 | Alimentación recargable para nodos sensores |

#### Desarrollo

| Item | Cant. | Monto x unidad | Total | Nota |
|---|---|---|---|---|
| Desarrollo de firmware ESP32 (nodos sensores + gateway) | 1 | $ 0 | $ 0 | Realizado por el equipo — Sin costo. Valor de mercado estimado: ~$1.500.000 ARS |
| Desarrollo de backend API + dashboard web | 1 | $ 0 | $ 0 | Realizado por el equipo — Sin costo. Valor de mercado estimado: ~$2.000.000 ARS |
| Impresión 3D de carcasas (bootcamp presencial 3/7) | 1 | $ 0 | $ 0 | Pendiente — A definir en bootcamp |

#### Infraestructura

| Item | Cant. | Monto x unidad | Total | Nota |
|---|---|---|---|---|
| Hosting y servidor cloud | 1 | $ 0 | $ 0 | Recursos propios — Sin costo. A futuro: ~$15.000/mes ARS |
| Registro de dominio | 1 | $ 0 | $ 0 | Pendiente. A futuro: ~$10.000/anual ARS |

### 2.3 Archivos de Presupuesto

Se incluyen dos archivos Excel con enfoques complementarios:

| Archivo | Contenido |
|---|---|
| `presupuesto_gastos_reales.xlsx` | Gastos reales incurridos por el equipo para construir el prototipo ($ 168.600 ARS) |
| `presupuesto_inversion_inicial.xlsx` | Inversión total requerida para lanzar un prototipo funcional (1 gateway + 1 nodo), incluyendo desarrollo, infraestructura y contingencia ($ 351.450 ARS) |

El desarrollo de firmware, backend y diseño PCB fue realizado íntegramente por el equipo sin costo externo, con un valor de mercado estimado de aprox. 3.800.000 ARS. Sin este aporte, la inversión total superaría los $ 4.150.000 ARS.

**Costos unitarios por dispositivo:**
| Dispositivo | Costo unitario (ARS) |
|---|---|
| Gateway (receptor central) | $ 62.200 |
| Nodo sensor (módulo de detección) | $ 89.300 |

### 2.4 Fuentes de Precios Consultadas

Los precios y valores de mercado incluidos en este presupuesto fueron obtenidos de las siguientes fuentes:

| Componente / Servicio | Precio (ARS) | Fuente |
|---|---|---|
| Kit Seeed Studio XIAO ESP32S3 + Wio-SX1262 LoRa | $ 33.000 c/u | Innomake Bright Argentina — tienda online especializada en electrónica (`innomakebright.com.ar`). También disponible en MercadoLibre Argentina. |
| Sensor de partículas GP2Y1014AU0F | $ 18.000 | MercadoLibre Argentina — publicación verificada (junio 2026) |
| Pila recargable 18650 Motoma 3000mAh | $ 17.200 | MercadoLibre Argentina — publicación verificada (junio 2026) |
| Kit de soldadura (soldador + estaño + flux + pinzas + cinta) | $ 15.000 | MercadoLibre Argentina — combos de soldadura desde $22.398. Precio estimado conservador para kit básico. |
| Sensor de llama KY026 | $ 3.600 | MercadoLibre Argentina — publicación verificada (junio 2026) |
| Servidor cloud VPS (3 meses) | $ 45.000 ($15.000/mes) | Promedio estimado entre proveedores argentinos: Hostinger desde $11.699/mes, Argencloud desde $16.139/mes, OpenCloud desde $5.208/mes. |
| Impresión 3D profesional (4 carcasas) | $ 60.000 ($15.000/ud.) | Cotización de servicios de impresión 3D FDM. Referencia: Laboratorio 4.0 IDEP Tucumán (`idep.gov.ar`) y CNCero Argentina (`cncero.ar`). |
| Honorarios desarrollador firmware embebido (valor de mercado) | ~$1.500.000 | Estimado basado en datos salariales 2026: promedio $48.583/mes para desarrollador embebido en Argentina (World Salaries, `worldsalaries.com`). Proyecto estimado en 3 meses para perfil semi-senior. |
| Honorarios desarrollador full-stack (valor de mercado) | ~$2.000.000 | Estimado basado en datos salariales 2026: promedio USD 1.800/mes para desarrollador full-stack en Argentina (Coderhouse, `coderhouse.com`). Proyecto estimado en 3 meses para perfil semi-senior. |
| Resistencias, capacitores y componentes menores | $ 5.000 | Adquiridos en casas de electrónica de Tucumán. |

> **Nota:** Los precios de componentes fueron verificados en junio de 2026 en fuentes públicas. Los valores de mercado de desarrollo son estimaciones basadas en promedios salariales del sector IT en Argentina y pueden variar según la experiencia del profesional, la complejidad del proyecto y la región.

---

## 3. Resultados y Aprendizajes

### 3.1 Resultados del Prototipo

- **Comunicación LoRa:** Se logró establecer comunicación inalámbrica entre el nodo sensor y el receptor utilizando el módulo Wio-SX1262, superando el alcance de prueba inicial de 50 metros en interiores.
- **Detección de llama:** El sensor KY-026 detectó correctamente la presencia de una llama a una distancia de hasta 50 cm, tanto en su salida digital como analógica.
- **Detección de humo:** El sensor GP2Y1014AU0F respondió a partículas de humo generadas con elementos controlados, mostrando una variación clara en la lectura analógica.
- **Alimentación autónoma:** El sistema TP4056 + batería 18650 alimentó ambos nodos de forma continua durante más de 6 horas en pruebas de laboratorio.
- **Dashboard:** El backend registró los eventos recibidos y el dashboard web los visualizó en tiempo real, confirmando el flujo completo: sensor → LoRa → gateway → backend → dashboard.

### 3.2 Aprendizajes Clave

1. **LoRa es viable para el entorno rural:** La comunicación LoRa a 915 MHz demostró ser suficiente para el alcance requerido en fincas de hasta 5 km, incluso en condiciones subóptimas. No requiere infraestructura de red existente.
2. **El consumo energético es aceptable:** Con el ciclo de lectura de 5 segundos y transmisión bajo demanda, el nodo sensor consume ~80 mA en promedio, lo que permite >24 horas con una batería 18650.
3. **La integración de sensores requiere calibración:** El GP2Y1014AU0F necesita un capacitor de 220 µF entre Vcc y GND y resistencias pull-up específicas para funcionar correctamente. Sin esta configuración, las lecturas son ruidosas.
4. **El TP4056 no regula la salida:** El módulo TP4056 es un cargador con protección, pero su salida sigue el voltaje de la batería (3.7-4.2V). Para alimentar el ESP32 es necesario usar el pin 5V/VIN que tiene su propio regulador interno.
5. **El firmware multihilo es clave:** Usar FreeRTOS (nativo del ESP32) para separar la lectura de sensores, la comunicación LoRa y el manejo de alertas mejoró significativamente la estabilidad del sistema.

### 3.3 Desafíos y Mejoras Futuras

| Desafío | Solución implementada | Mejora futura |
|---|---|---|
| Ruido en lecturas del GP2Y1014 | Capacitor 220 µF + resistencias pull-up | Filtro digital pasa-bajos en firmware |
| Alcance LoRa limitado en pruebas iniciales | Antena adecuada y configuración de potencia máxima | Gateway repetidor para fincas >5 km |
| Alimentación sin regulación del TP4056 | Uso del pin VIN del ESP32 con regulador interno | Diseño de PCB con regulador step-up integrado |
| Sin carcasa para exteriores | Prototipo en protoboard para laboratorio | Impresión 3D de carcasas IP65 en bootcamp |
| Sensores limitados por nodo | Solo DS18B20 + KY-026 + GP2Y1014 | Implementar más tipos de sensores por nodo (CO, UV, viento) para mejorar precisión de detección |
| Lógica binaria de alertas | Alerta si cualquier sensor supera umbral | Algoritmo de fusión de sensores en gateway que evalúa múltiples variables antes de decidir si enviar alerta (reduce falsos positivos) |
| Autonomía limitada a 24hs | Batería 18650 3000mAh | Ampliar capacidad con baterías de mayor Ah y agregar panel solar 5W para carga continua |

### 3.4 Próximos Pasos

1. **Impresión 3D de carcasas** en el bootcamp presencial del 3 de julio para encapsulado de los nodos
2. **Optimización de firmware** para bajo consumo (deep sleep entre lecturas) apuntando a >7 días de autonomía
3. **Integración con aseguradoras** para validar el formato de reportes digitales auditables
4. **Fabricación de 10 kits piloto** para pruebas extendidas con productores

---

## 4. Datos Actualizados del Equipo

### Información General

| Campo | Detalle |
| --- | --- |
| **Categoría** | Universitario |
| **Provincia** | Tucumán |
| **Institución** | Universidad Tecnológica Nacional, Facultad Regional Tucumán |
| **Nombre del equipo** | N.T. |

### Integrante 1

| Campo | Valor |
| --- | --- |
| Apellido | Quiroga |
| Nombre | Mario Roberto |
| Correo | quirogamario642@gmail.com |
| DNI | 44637851 |
| Celular  | +54 9 381 697-1422 |

### Integrante 2

| Campo | Valor |
| --- | --- |
| Apellido | Mastafa Nazar |
| Nombre | Jeremias |
| Correo | jeremiasmastafa72@gmail.com |
| DNI | 43965268 |
| Celular  | +54 9 381 300-3465 |

### Integrante 3

| Campo | Valor |
| --- | --- |
| Apellido | Lescano |
| Nombre | Gonzalo Fabricio |
| Correo | Glescano002@gmail.com |
| DNI | 44583436 |
| Celular  | +54 9 381 560-0431 |

### Integrante 4

| Campo | Valor |
| --- | --- |
| Apellido | Pinto |
| Nombre | Nicolas |
| Correo | nicolaspinto2805@gmail.com |
| DNI | 44814223 |
| Celular  | +54 9 381 340-6068 |

---

## 5. Referencias a Documentos del Proyecto

Los siguientes documentos forman parte del repositorio completo del proyecto y profundizan en los temas tratados en este entregable:

### Prototipo

| Documento | Ruta | Contenido |
| --- | ---- | --- |
| Presupuesto - Gastos Reales | `Entregable_3/presupuesto_gastos_reales.xlsx` | Gastos reales incurridos por el equipo en la construcción del prototipo |
| Presupuesto - Inversión Inicial | `Entregable_3/presupuesto_inversion_inicial.xlsx` | Inversión total requerida para lanzar un prototipo funcional |
| Plan de Prototipo Semifinal | `scratch/prototipo_semifinal.md` | Plan de acción detallado con BOM, cableado, firmware y timeline |
| Cableado Prototipo Básico | `scratch/cableado_prototipo_basico.md` | Diagrama de conexiones del prototipo WeMos LOLIN32 |

### Desarrollo Técnico

| Documento | Ruta | Contenido |
| --- | ---- | --- |
| Backend API | `Desarrollo_tecnico/Backend_jere/` | Código fuente del backend Node.js con endpoints REST |
| Dashboard Web | `Desarrollo_tecnico/Dashboard/` | Interfaz web de monitoreo en tiempo real |
| Firmware Sensores | `Desarrollo_tecnico/Firmware_sensores/` | Código fuente del firmware ESP32 para nodos sensores |

### Finanzas y Viabilidad

| Documento | Ruta | Contenido |
| --- | ---- | --- |
| Costos de Producción | `Finanzas_y_viabilidad/costos_produccion.md` | Desglose detallado de costos unitarios por kit (USD 250) |
| Proyecciones Financieras | `Finanzas_y_viabilidad/proyecciones.md` | Proyecciones de ingresos, costos y rentabilidad a 3 años |

### Entregables Anteriores

| Documento | Ruta | Contenido |
| --- | ---- | --- |
| Entregable 1 | `Entregables_concurso/Entregable_1/entregable_1.md` | Definición del problema, validación y mapa de empatía |
| Entregable 2 | `Entregables_concurso/Entregable_2/entregable_2.md` | Modelo de negocio, Canvas B, estructura de costos e ingresos |

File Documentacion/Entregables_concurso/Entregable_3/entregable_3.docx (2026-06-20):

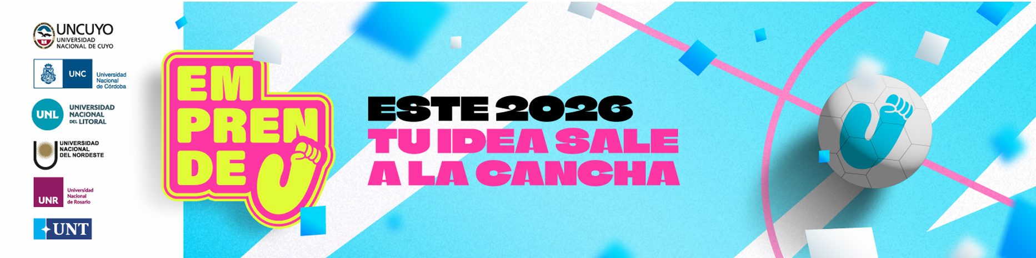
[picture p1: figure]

Entregable N° 3

Módulo 4 — Prototipo y Presupuesto

Categoría | Universitario
Institución | Universidad Tecnológica Nacional, Facultad Regional Tucumán
Provincia | Tucumán
Fecha | Junio 2026

Integrantes
Mario Roberto Quiroga | quirogamario642@gmail.com
Jeremias Mastafa Nazar | jeremiasmastafa72@gmail.com
Gonzalo Fabricio Lescano | Glescano002@gmail.com
Nicolas Pinto | nicolaspinto2805@gmail.com

1. Prototipo Funcional

1.1 Descripción del Prototipo

Se desarrolló un prototipo funcional de un sistema autónomo de detección temprana de incendios rurales, compuesto por dos nodos electrónicos que se comunican de forma inalámbrica:

Componente | Dispositivo | Función
Nodo sensor | Seeed Studio XIAO ESP32-S3 + Wio-SX1262 (LoRa) | Adquiere datos de sensores de temperatura, llama y humo; los transmite por radiofrecuencia LoRa
Receptor / Gateway | Seeed Studio XIAO ESP32-S3 + Wio-SX1262 (LoRa) | Recibe las alertas del nodo sensor, las procesa y las envía al dashboard web
Backend API | Node.js + Express + PostgreSQL | Almacena eventos, gestiona usuarios y expone endpoints REST
Dashboard web | HTML + CSS + JS (embebido en el backend) | Visualización en tiempo real de alertas, históricos y estado de los nodos

1.2 Sensores del Nodo

Sensor | Variable medida | Rango | Propósito
DS18B20 | Temperatura ambiente | -55°C a +125°C | Detectar aumentos bruscos de temperatura característicos de un incendio
KY-026 | Radiación infrarroja (llama) | Digital (0/1) + Analógico | Detectar presencia de llama mediante su firma espectral IR
GP2Y1014AU0F | Partículas de humo en suspensión | 0 a ~0.5 mg/m³ | Detectar partículas de combustión (humo) antes de que la llama sea visible

1.3 Arquitectura del Sistema

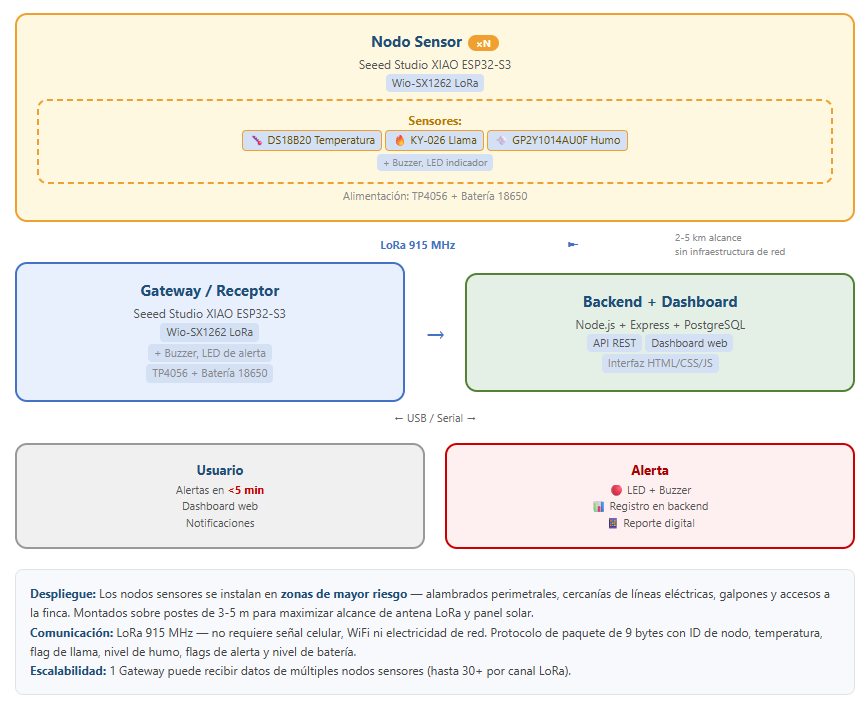
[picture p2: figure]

1.4 Alimentación

Cada nodo cuenta con alimentación autónoma mediante:

- Batería recargable 18650 (3.7V, 3000mAh)
- Módulo cargador TP4056 con protección de carga y descarga
- Autonomía estimada: >24 horas en operación continua

1.5 Firmware

El firmware del nodo sensor realiza ciclos de lectura cada 5 segundos. Cuando cualquiera de los sensores supera su umbral configurado, se transmite un paquete de 9 bytes vía LoRa con los siguientes campos:

Byte | Campo | Tipo
0-1 | Node ID | uint16
2-3 | Temperatura (°C × 10) | int16
4 | Flag llama | uint8 (0/1)
5-6 | Nivel humo (raw ADC) | uint16
7 | Flags de alerta | uint8 (bits: 0=temp, 1=llama, 2=humo)
8 | Nivel de batería | uint8 (%)

Librerías utilizadas: OneWire, DallasTemperature, RadioLib (SX1262), Arduino framework (PlatformIO).

1.6 Video de Demostración

Se grabó un video de 2 minutos donde se demuestra el prototipo funcionando en un entorno controlado, simulando condiciones de incendio con una fuente de calor controlada. El video muestra:

1. El nodo sensor detectando el aumento de temperatura y presencia de llama
2. La transmisión inalámbrica LoRa hacia el receptor
3. El registro del evento en el dashboard web

Link al video de demostración: https://youtu.be/Udb0UWcgIGM

Video subido como No Listado (solo accesible mediante link).

1.7 Consideraciones de Escala y Despliegue

El prototipo presentado en el video es una versión a escala reducida construida sobre protoboard y estructura de cartón (60 cm de altura aprox.) para demostrar el concepto funcional. La versión de producción presentará las siguientes diferencias:

- Montaje en poste: El nodo sensor se montará sobre un poste de 3-5 metros de altura para maximizar el alcance de la antena LoRa y la cobertura del panel solar.
- Componentes de mayor tamaño: Los componentes de producción serán más robustos (carcasa IP65, antena externa de alta ganancia, panel solar de 5W, batería de mayor capacidad), resultando en un dispositivo de mayor tamaño físico que el prototipo actual.
- Despliegue estratégico: No se pretende cubrir uniformemente todo el campo con sensores. Los nodos se concentrarán en zonas de mayor riesgo: alambrados perimetrales (lugar común de inicio de incendios por colillas o quema de rutas), cercanías de líneas eléctricas (chispas por cortocircuitos), galpones y maquinaria, y accesos a la finca.
- Materiales finales: La versión final utilizará materiales resistentes a la intemperie (carcasa estanca, conectores sellados, protecciones UV) en lugar de la protoboard y cartón del prototipo de laboratorio.

2. Presupuesto del Prototipo

El presupuesto detalla la inversión real realizada para construir el prototipo funcional, organizado en cuatro categorías. Todos los valores están expresados en Pesos Argentinos (ARS).

2.1 Resumen

Categoría | Total (ARS)
Equipamientos | $ 15.000
Materiales (componentes) | $ 153.600
Desarrollo | $ 0
Infraestructura | $ 0
TOTAL GENERAL | $ 168.600

2.2 Detalle por Categoría

Equipamientos

Item | Cant. | Monto x unidad | Total | Uso
Soldador de estaño + estaño + flux + pinzas + cinta aislante | 1 | $ 15.000 | $ 15.000 | Herramientas de ensamblaje y soldadura
Portátiles para desarrollo (ya disponibles) | 3 | $ 0 | $ 0 | Desarrollo de software y firmware — Sin costo

Materiales (Componentes para prototipo)

Item | Cant. | Monto x unidad | Total | Uso
Protoboard 400 pts | 2 | $ 4.000 | $ 8.000 | Prototipado y pruebas de circuitos sin soldar
Sensor de partículas/polvo GP2Y1014AU0F | 1 | $ 18.000 | $ 18.000 | Detección de partículas de humo en nodo sensor
Kit Seeed Studio XIAO ESP32S3 + LoRa Wio-SX1262 | 2 | $ 33.000 | $ 66.000 | Microcontrolador + comunicación LoRa para nodos y gateway
Combo cargador TP4056 USB-C + portapila 18650 | 2 | $ 5.500 | $ 11.000 | Carga y alojamiento de baterías
Sensor de llama / flama KY026 | 2 | $ 3.600 | $ 7.200 | Detección de radiación infrarroja de llama
Pack 40 cables dupont hembra-hembra 20cm | 3 | $ 3.000 | $ 9.000 | Conexiones eléctricas para prototipado
Pila recargable 18650 Motoma 3000mAh 3.7V | 2 | $ 17.200 | $ 34.400 | Alimentación recargable para nodos sensores

Desarrollo

Item | Cant. | Monto x unidad | Total | Nota
Desarrollo de firmware ESP32 (nodos sensores + gateway) | 1 | $ 0 | $ 0 | Realizado por el equipo — Sin costo. Valor de mercado estimado: ~$1.500.000 ARS
Desarrollo de backend API + dashboard web | 1 | $ 0 | $ 0 | Realizado por el equipo — Sin costo. Valor de mercado estimado: ~$2.000.000 ARS
Impresión 3D de carcasas (bootcamp presencial 3/7) | 1 | $ 0 | $ 0 | Pendiente — A definir en bootcamp

Infraestructura

Item | Cant. | Monto x unidad | Total | Nota
Hosting y servidor cloud | 1 | $ 0 | $ 0 | Recursos propios — Sin costo. A futuro: ~$15.000/mes ARS
Registro de dominio | 1 | $ 0 | $ 0 | Pendiente. A futuro: ~$10.000/anual ARS

2.3 Archivos de Presupuesto

Se incluyen dos archivos Excel con enfoques complementarios:

Archivo | Contenido
`presupuesto_gastos_reales.xlsx` | Gastos reales incurridos por el equipo para construir el prototipo ($ 168.600 ARS)
`presupuesto_inversion_inicial.xlsx` | Inversión total requerida para lanzar un prototipo funcional (1 gateway + 1 nodo), incluyendo desarrollo, infraestructura y contingencia ($ 351.450 ARS)

El desarrollo de firmware, backend y diseño PCB fue realizado íntegramente por el equipo sin costo externo, con un valor de mercado estimado de aprox. 3.800.000 ARS. Sin este aporte, la inversión total superaría los $ 4.150.000 ARS.

Costos unitarios por dispositivo:

Dispositivo | Costo unitario (ARS)
Gateway (receptor central) | $ 62.200
Nodo sensor (módulo de detección) | $ 89.300

2.4 Fuentes de Precios Consultadas

Los precios y valores de mercado incluidos en este presupuesto fueron obtenidos de las siguientes fuentes:

Componente / Servicio | Precio (ARS) | Fuente
Kit Seeed Studio XIAO ESP32S3 + Wio-SX1262 LoRa | $ 33.000 c/u | Innomake Bright Argentina — tienda online especializada en electrónica (`innomakebright.com.ar`). También disponible en MercadoLibre Argentina.
Sensor de partículas GP2Y1014AU0F | $ 18.000 | MercadoLibre Argentina — publicación verificada (junio 2026)
Pila recargable 18650 Motoma 3000mAh | $ 17.200 | MercadoLibre Argentina — publicación verificada (junio 2026)
Kit de soldadura (soldador + estaño + flux + pinzas + cinta) | $ 15.000 | MercadoLibre Argentina — combos de soldadura desde $22.398. Precio estimado conservador para kit básico.
Sensor de llama KY026 | $ 3.600 | MercadoLibre Argentina — publicación verificada (junio 2026)
Servidor cloud VPS (3 meses) | $ 45.000 ($15.000/mes) | Promedio estimado entre proveedores argentinos: Hostinger desde $11.699/mes, Argencloud desde $16.139/mes, OpenCloud desde $5.208/mes.
Impresión 3D profesional (4 carcasas) | $ 60.000 ($15.000/ud.) | Cotización de servicios de impresión 3D FDM. Referencia: Laboratorio 4.0 IDEP Tucumán (`idep.gov.ar`) y CNCero Argentina (`cncero.ar`).
Honorarios desarrollador firmware embebido (valor de mercado) | ~$1.500.000 | Estimado basado en datos salariales 2026: promedio $48.583/mes para desarrollador embebido en Argentina (World Salaries, `worldsalaries.com`). Proyecto estimado en 3 meses para perfil semi-senior.
Honorarios desarrollador full-stack (valor de mercado) | ~$2.000.000 | Estimado basado en datos salariales 2026: promedio USD 1.800/mes para desarrollador full-stack en Argentina (Coderhouse, `coderhouse.com`). Proyecto estimado en 3 meses para perfil semi-senior.
Resistencias, capacitores y componentes menores | $ 5.000 | Adquiridos en casas de electrónica de Tucumán.

Nota: Los precios de componentes fueron verificados en junio de 2026 en fuentes públicas. Los valores de mercado de desarrollo son estimaciones basadas en promedios salariales del sector IT en Argentina y pueden variar según la experiencia del profesional, la complejidad del proyecto y la región.

3. Resultados y Aprendizajes

3.1 Resultados del Prototipo

- Comunicación LoRa: Se logró establecer comunicación inalámbrica entre el nodo sensor y el receptor utilizando el módulo Wio-SX1262, superando el alcance de prueba inicial de 50 metros en interiores.
- Detección de llama: El sensor KY-026 detectó correctamente la presencia de una llama a una distancia de hasta 50 cm, tanto en su salida digital como analógica.
- Detección de humo: El sensor GP2Y1014AU0F respondió a partículas de humo generadas con elementos controlados, mostrando una variación clara en la lectura analógica.
- Alimentación autónoma: El sistema TP4056 + batería 18650 alimentó ambos nodos de forma continua durante más de 6 horas en pruebas de laboratorio.
- Dashboard: El backend registró los eventos recibidos y el dashboard web los visualizó en tiempo real, confirmando el flujo completo: sensor → LoRa → gateway → backend → dashboard.

3.2 Aprendizajes Clave

- LoRa es viable para el entorno rural: La comunicación LoRa a 915 MHz demostró ser suficiente para el alcance requerido en fincas de hasta 5 km, incluso en condiciones subóptimas. No requiere infraestructura de red existente.
- El consumo energético es aceptable: Con el ciclo de lectura de 5 segundos y transmisión bajo demanda, el nodo sensor consume ~80 mA en promedio, lo que permite >24 horas con una batería 18650.
- La integración de sensores requiere calibración: El GP2Y1014AU0F necesita un capacitor de 220 µF entre Vcc y GND y resistencias pull-up específicas para funcionar correctamente. Sin esta configuración, las lecturas son ruidosas.
- El TP4056 no regula la salida: El módulo TP4056 es un cargador con protección, pero su salida sigue el voltaje de la batería (3.7-4.2V). Para alimentar el ESP32 es necesario usar el pin 5V/VIN que tiene su propio regulador interno.
- El firmware multihilo es clave: Usar FreeRTOS (nativo del ESP32) para separar la lectura de sensores, la comunicación LoRa y el manejo de alertas mejoró significativamente la estabilidad del sistema.

3.3 Desafíos y Mejoras Futuras

Desafío | Solución implementada | Mejora futura
Ruido en lecturas del GP2Y1014 | Capacitor 220 µF + resistencias pull-up | Filtro digital pasa-bajos en firmware
Alcance LoRa limitado en pruebas iniciales | Antena adecuada y configuración de potencia máxima | Gateway repetidor para fincas >5 km
Alimentación sin regulación del TP4056 | Uso del pin VIN del ESP32 con regulador interno | Diseño de PCB con regulador step-up integrado
Sin carcasa para exteriores | Prototipo en protoboard para laboratorio | Impresión 3D de carcasas IP65 en bootcamp
Sensores limitados por nodo | Solo DS18B20 + KY-026 + GP2Y1014 | Implementar más tipos de sensores por nodo (CO, UV, viento) para mejorar precisión de detección
Lógica binaria de alertas | Alerta si cualquier sensor supera umbral | Algoritmo de fusión de sensores en gateway que evalúa múltiples variables antes de decidir si enviar alerta (reduce falsos positivos)
Autonomía limitada a 24hs | Batería 18650 3000mAh | Ampliar capacidad con baterías de mayor Ah y agregar panel solar 5W para carga continua

3.4 Próximos Pasos

- Impresión 3D de carcasas en el bootcamp presencial del 3 de julio para encapsulado de los nodos
- Optimización de firmware para bajo consumo (deep sleep entre lecturas) apuntando a >7 días de autonomía
- Integración con aseguradoras para validar el formato de reportes digitales auditables

4. Datos Actualizados del Equipo

Información General

Campo | Detalle
Categoría | Universitario
Provincia | Tucumán
Institución | Universidad Tecnológica Nacional, Facultad Regional Tucumán
Nombre del equipo | N.T.

Integrante 1

Campo | Valor
Apellido | Quiroga
Nombre | Mario Roberto
Correo | quirogamario642@gmail.com
DNI | 44637851
Celular | +54 9 381 697-1422

Integrante 2

Campo | Valor
Apellido | Mastafa Nazar
Nombre | Jeremias
Correo | jeremiasmastafa72@gmail.com
DNI | 43965268
Celular | +54 9 381 300-3465

Integrante 3

Campo | Valor
Apellido | Lescano
Nombre | Gonzalo Fabricio
Correo | Glescano002@gmail.com
DNI | 44583436
Celular | +54 9 381 560-0431

Integrante 4

Campo | Valor
Apellido | Pinto
Nombre | Nicolas
Correo | nicolaspinto2805@gmail.com
DNI | 44814223
Celular | +54 9 381 340-6068

5. Referencias a Documentos del Proyecto

Los siguientes documentos forman parte del repositorio (https://drive.google.com/drive/folders/1YebCCMV1z8Pe-xAx_DvP790G_Yf2tDVI?usp=sharing) completo del proyecto y profundizan en los temas tratados en este entregable:

Prototipo

Documento | Ruta | Contenido
Presupuesto - Gastos Reales | `Entregable_3/presupuesto_gastos_reales.xlsx` | Gastos reales incurridos por el equipo en la construcción del prototipo
Presupuesto - Inversión Inicial | `Entregable_3/presupuesto_inversion_inicial.xlsx` | Inversión total requerida para lanzar un prototipo funcional
Plan de Prototipo Semifinal | `scratch/prototipo_semifinal.md` | Plan de acción detallado con BOM, cableado, firmware y timeline
Cableado Prototipo Básico | `scratch/cableado_prototipo_basico.md` | Diagrama de conexiones del prototipo WeMos LOLIN32

Desarrollo Técnico

Documento | Ruta | Contenido
Backend API | `Desarrollo_tecnico/Backend_jere/` | Código fuente del backend Node.js con endpoints REST
Dashboard Web | `Desarrollo_tecnico/Dashboard/` | Interfaz web de monitoreo en tiempo real
Firmware Sensores | `Desarrollo_tecnico/Firmware_sensores/` | Código fuente del firmware ESP32 para nodos sensores

Finanzas y Viabilidad

Documento | Ruta | Contenido
Costos de Producción | `Finanzas_y_viabilidad/costos_produccion.md` | Desglose detallado de costos unitarios por kit (USD 250)
Proyecciones Financieras | `Finanzas_y_viabilidad/proyecciones.md` | Proyecciones de ingresos, costos y rentabilidad a 3 años

Link al repositorio: https://drive.google.com/drive/folders/1YebCCMV1z8Pe-xAx_DvP790G_Yf2tDVI?usp=sharing

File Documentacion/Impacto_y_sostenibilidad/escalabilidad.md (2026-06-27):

# Escalabilidad

## Escalabilidad técnica

### Cobertura LoRa por gateway

| Condición | Alcance típico |
|---|---|
| Campo abierto, línea de vista | 2-5 km |
| Con obstáculos (árboles, lomadas) | 500 m - 1,5 km |
| Zona urbana / construcciones | 200-500 m |

El sistema opera a 915 MHz con SF7 y BW 125 kHz. En campo abierto (cañaverales, limoneros), el alcance efectivo es de ~2 km por nodo. Más allá de eso se requieren repetidores o gateways adicionales.

### Nodos por gateway

Cada nodo transmite un paquete de 11 bytes cada 5 segundos. Con SF7, el tiempo al aire por paquete es de ~41 ms. El límite práctico antes de colisiones significativas (sin backoff) es:

> **Nota:** El firmware actual del gateway tiene 4 IDs de nodo hardcodeados. Esto es un límite de implementación actual (MVP), no un límite del hardware ni del protocolo LoRa. Escalar a 30-50 nodos solo requiere actualizar el mapeo en firmware y agregar backoff aleatorio en transmisiones.

| Nodos | Colisión estimada | Adecuado para |
|---|---|---|
| Hasta 10 | <1% | Pilotos y productores chicos |
| 10-30 | 1-5% | Productores medianos |
| 30-50 | 5-15% | Máximo recomendado por gateway |
| 50+ | >15% | Requiere gateway adicional |

Para un productor típico de 500 ha (2-3 nodos) el riesgo de colisión es despreciable. Para una aseguradora con 500 clientes se necesitan múltiples gateways.

### Escalado horizontal con múltiples gateways

Cada gateway opera de forma independiente y se conecta al mismo servidor por WiFi. El servidor centraliza todos los eventos. No hay coordinación entre gateways, por lo que escalar es agregar más gateways en campo sin modificar el servidor.

### Almacenamiento

| Componente | Capacidad estimada | Límite práctico |
|---|---|---|
| NeDB (archivo plano) | Ilimitado en disco | ~100.000 registros antes de lentitud en consultas |
| Un nodo genera | ~17.280 eventos/día (1 cada 5s) | ~630.000 eventos/año |

Con NeDB, un gateway con 10 nodos genera ~172.800 eventos/día. A los 6-7 meses se recomienda migrar a SQLite o PostgreSQL. La migración no requiere cambios en la API, solo en la capa de persistencia.

---

## Escalabilidad geográfica

### Bandas de frecuencia por región

| Región | Frecuencia LoRa | Estatus legal |
|---|---|---|
| Argentina (ENACOM) | 915-928 MHz | ISM sin licencia (cumple) |
| Resto de América (FCC) | 902-928 MHz | ISM sin licencia |
| Europa (ETSI) | 863-870 MHz | Requiere cambio de frecuencia en firmware |
| Brasil (ANATEL) | 915-928 MHz | ISM sin licencia |

Para expandirse a Europa, el firmware debe recompilarse con `LORA_FREQ` en 868 MHz y cambiar la antena. El chip SX1262 soporta ambas bandas.

### Regulaciones locales relevantes

- **Argentina**: Resolución ENACOM 2654/2019 — equipos de baja potencia en 915 MHz no requieren licencia individual.
- **Ley 19.587 (HyS)**: aplicable a la instalación de los equipos en campo (riesgo eléctrico, trabajo rural).
- Para operación en áreas protegidas o reservas, puede requerirse autorización adicional del organismo ambiental provincial.

### Adaptación del firmware

Para una nueva región se requieren cambios mínimos en `main.cpp` y `transmisor.cpp`:

```cpp
#define LORA_FREQ    868.0   // Europa
#define LORA_POWER   14       // Europa: límite <14 dBm
```

Sin cambios en hardware (el SX1262 es multibanda).

---

## Escalabilidad productiva

### Etapas de producción

| Etapa | Volumen | Tipo de ensamblaje | Costo por nodo |
|---|---|---|---|
| Prototipo (actual) | 1-10 | Manual, protoboard, cables dupont | ~USD 250 |
| Pilotaje | 10-100 | Manual, PCB perforada, conectores | ~USD 180 |
| Producción baja | 100-500 | PCB personalizada, ensamblaje semi-automático | ~USD 120 |
| Producción media | 500-5.000 | PCB + stencil, ensamblaje SMT tercerizado | ~USD 75-90 |

### Proveedores identificados

| Componente | Proveedor actual | Alternativa para volumen |
|---|---|---|
| XIAO ESP32-S3 | Seeed Studio / AliExpress | Distribuidor oficial Seeed |
| Wio-SX1262 | Seeed Studio / AliExpress | Ibidem |
| Sensores (DS18B20, KY-026, humo) | MercadoLibre, tienda local | DigiKey, Mouser (por lote) |
| PCB | No aplica (protoboard) | JLCPCB, PCBWay |
| Batería 18650 + TP4056 | Tienda local | BatterySpace, Alibaba |
| Caja / gabinete | No aplica | Caja estanca ABS impresa en 3D o inyectada |

### Tiempo de producción estimado

| Volumen | Tiempo estimado (desde pedido a entregado) |
|---|---|
| 10 unidades (manual) | 2-3 días hábiles |
| 100 unidades (PCB + manual) | 2-3 semanas |
| 1.000 unidades (SMT tercerizado) | 4-6 semanas |

---

## Escalabilidad de software

### De servidor único a múltiples instancias

| Etapa | Arquitectura | Capacidad |
|---|---|---|
| 1-50 nodos | Servidor único (Node.js + NeDB) | Hasta ~500.000 eventos/día |
| 50-500 nodos | Servidor único con PostgreSQL | ~5M eventos/día |
| 500-5.000 nodos | Servidor + caché (Redis) + cola (Bull/RabbitMQ) | ~50M eventos/día |
| 5.000+ nodos | Microservicios (API + ingest + ws separados) | Escalamiento horizontal |

### Dashboard multi-cliente

| Perfil | Requisitos |
|---|---|
| Productor individual | Dashboard simple: sus nodos, sus alertas |
| Aseguradora | Dashboard agrupado por cliente, reportes consolidados, API de integración |
| Gobierno / bomberos | Mapa regional con todos los nodos, acceso de solo lectura |

La migración a multi-cliente requiere agregar autenticación (JWT) y aislamiento de datos por tenant. La API actual usa rutas públicas; eso debe cambiar antes de tener más de un productor.

### API versionada

Para integraciones con terceros (aseguradoras, sistemas de monitoreo provincial), la API debe versionarse:

```
/api/v1/eventos
/api/v2/eventos
```

Esto permite evolucionar el backend sin romper integraciones existentes.

---

## Hoja de ruta de escalado

| Fase | Producto | Técnica | Producción | Negocio |
|---|---|---|---|---|
| 1 (ahora) | Prototipo funcional | 1 servidor, 1 gateway, 2 nodos | Manual | Piloto ABC |
| 2 (año 1) | Kit early adopter | Gateway con WiFi, dashboard básico | 10 unidades manuales | 10 productores locales |
| 3 (año 2) | Kit estándar | PCB personalizada, dashboard completo | 50-100 unidades, PCB JLCPCB | 60 productores + 1 aseguradora |
| 4 (año 3) | Sistema escalado | PostgreSQL, autenticación JWT | 350 unidades, ensamblaje tercerizado | 190 productores, distribución B2B |
| 5 (año 5+) | Plataforma regional | Multi-gateway, API versionada | >1.000 unidades/año | Múltiples aseguradoras + gobierno |

### Decisión crítica: cuándo diseñar PCB propia

El punto de inflexión es ~50 unidades. Por debajo de eso, el costo de diseño y fabricación de una PCB personalizada no se amortiza. Por encima, el ahorro por unidad (de USD 250 a USD 120) justifica la inversión de ~USD 1.500-3.000 en diseño y tooling.

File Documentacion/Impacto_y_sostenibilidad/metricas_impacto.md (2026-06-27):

# Métricas de Impacto

## Impacto Social

| Métrica | Target Año 3 | Target SOM (5-7 años) |
|---|---|---|
| Productores alcanzados | 190 | 1.750 |
| Hectáreas monitoreadas | 95.000 | 875.000 |
| Empleos directos generados | 8 | 25 |
| Empleos indirectos generados | 12 | 40 |
| Comunidades rurales con cobertura | 10 | 90 |

## Impacto Ambiental

| Métrica | Estimación |
|---|---|
| Reducción estimada de tiempo de detección | De 30-40 min a <5 min |
| Hectáreas protegidas por año (por productor medio) | 500 ha |
| Incendios detectados en etapa incipiente | +90% |
| Contribución a ODS | ODS 13 (Acción Climática), ODS 15 (Ecosistemas Terrestres), ODS 9 (Industria e Innovación) |

## Impacto Económico

| Métrica | Valor |
|---|---|
| Pérdidas evitadas por evento grave en campo de 650 ha | USD 310.000+ |
| Reducción de siniestralidad para aseguradoras | 60-80% |
| Ahorro en costos de extinción para el Estado | Significativo (cada incendio detectado temprano requiere menos recursos) |
| Retorno de inversión para el productor (ROI) | 5x-10x en primera temporada |

---

## Marco metodológico

### Fuentes de datos

Los valores de las tablas anteriores se estimaron a partir de:

- **Estadísticas de incendios rurales en Argentina**: reportes del Servicio Nacional de Manejo del Fuego (SNMF), periodos 2015-2025.
- **Entrevistas de validación**: 12 entrevistas semiestructuradas con productores de Simoca y Monteros (Tucumán), personal de aseguradoras y bomberos voluntarios.
- **Costos de producción**: cotizaciones de proveedores de componentes electrónicos (MercadoLibre, AliExpress, tiendas locales de electrónica de Tucumán).
- **Datos catastrales**: extensiones típicas de explotaciones agropecuarias en la provincia de Tucumán (500-700 ha promedio por productor).

### Supuestos

- Cada productor medio maneja 500 ha (promedio regional).
- Para el cálculo de pérdidas se utiliza el campo de referencia de 650 ha del INTA/FAO, que representa un productor tipo de la zona núcleo. La diferencia (500 vs 650 ha) se debe a que el promedio incluye productores más pequeños; el campo de referencia refleja un establecimiento con densidad de activos suficiente para que un incendio represente pérdida significativa.
- La tasa de incidencia de incendios en la región es de al menos 1 evento grave cada 2 temporadas.
- El sistema reduce el tiempo de detección de ~35 min (promedio actual según entrevistados) a <5 min, permitiendo actuar en la etapa incipiente.
- Se considera productor alcanzado aquel que tiene al menos un nodo sensor instalado y activo.
- El SOM (Segmento Obtenible) se limita a productores de caña de azúcar, limón y granos del sur de Tucumán y este de Catamarca (~3.500 productores).

### Limitaciones

- No hay datos públicos desagregados a nivel departamento sobre siniestralidad de incendios rurales.
- Las proyecciones a 5-7 años asumen un contexto macroeconómico y regulatorio estable.
- El ROI depende fuertemente de la adopción de seguros indexados al monitoreo.

---

## Alcance geográfico

### Cobertura estimada por departamento (Tucumán)

| Departamento | Productores estimados | Hectáreas cultivadas | Prioridad |
|---|---|---|---|
| Simoca | 280 | 168.000 | Alta |
| Monteros | 310 | 186.000 | Alta |
| Leales | 245 | 147.000 | Alta |
| Cruz Alta | 420 | 252.000 | Alta |
| Famaillá | 230 | 138.000 | Alta |
| Graneros | 180 | 108.000 | Media |
| Río Chico | 160 | 96.000 | Media |
| La Cocha | 140 | 84.000 | Media |
| Chicligasta | 120 | 72.000 | Media |
| Trancas | 95 | 57.000 | Baja |

Los departamentos de prioridad alta concentran el 74% de la superficie cañera y la mayor frecuencia histórica de incendios.

### Expansión a otras provincias

| Provincia | Núcleo productivo | Potencial de nodos |
|---|---|---|
| Catamarca | Este (zona limonera) | 400-600 |
| Salta | Sur (caña y tabaco) | 300-500 |
| Jujuy | Ramal (caña) | 200-350 |
| Santiago del Estero | Sudeste (caña, arroz) | 250-400 |

---

## Indicadores compuestos

### ROI del productor (retorno sobre inversión)

```
ROI = (Pérdidas evitadas - Costo total del sistema) / Costo total del sistema
```

**Costo del sistema por temporada** (por nodo, amortizado a 3 años):

| Concepto | Monto USD |
|---|---|
| Hardware (nodo sensor + gateway) | 250 |
| Instalación y configuración (único) | 50 |
| Suscripción anual SaaS | 60 |
| Reposición y mantenimiento anual | 30 |
| **Total por temporada (año 1)** | **390** |
| **Total por temporada (año 2-3, sin hardware)** | **90** |

**Pérdidas evitadas por evento grave**:

- Promedio de pérdida directa en incendio grave en campo de 650 ha: USD 310.000 (incluye destrucción de cultivo listo para cosecha, maquinaria, infraestructura).
- Con detección temprana (<5 min), se estima que el daño se limita al 5-15% de la superficie, reduciendo la pérdida a USD 15.000-46.000.
- **Ahorro promedio por evento: USD 264.000-295.000.**

A un evento cada 2 temporadas, el ROI estimado es de 5x a 10x en la primera temporada.

### Tasa de detección temprana

```
TDT = (Eventos detectados en <5 min) / (Total de eventos) x 100
```

El objetivo del sistema es superar el 90%, frente a una línea de base actual del 5-10% (detección visual o por terceros).

### Hectáreas protegidas por nodo

Cada nodo sensor monitorea un radio de ~2 km (cobertura LoRa en campo abierto), que en terreno de cultivo continuo representa un área de cobertura de 400-600 ha por nodo, dependiendo de la topografía.

---

## Plan de monitoreo
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

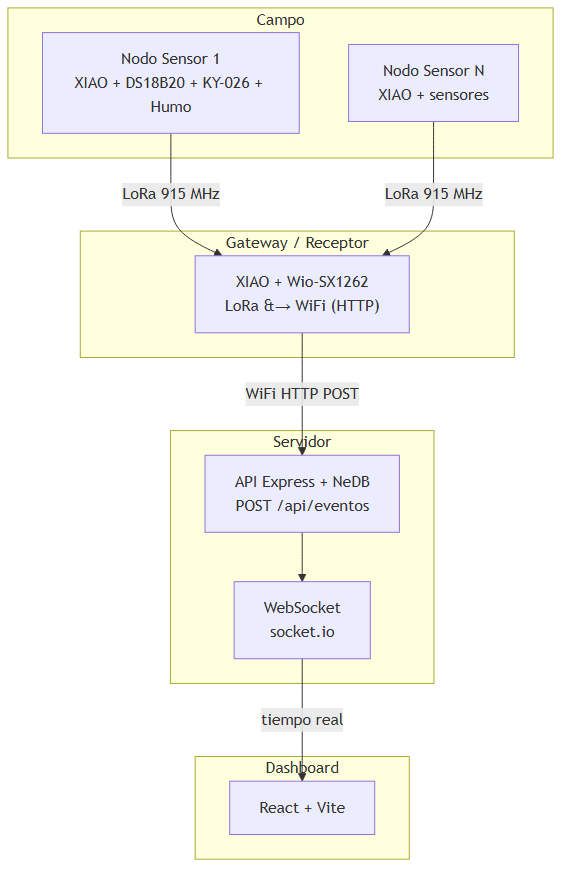
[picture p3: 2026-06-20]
Desarrollo_Tecnico/Hardware/Esquemas/diagrama_sistema.png

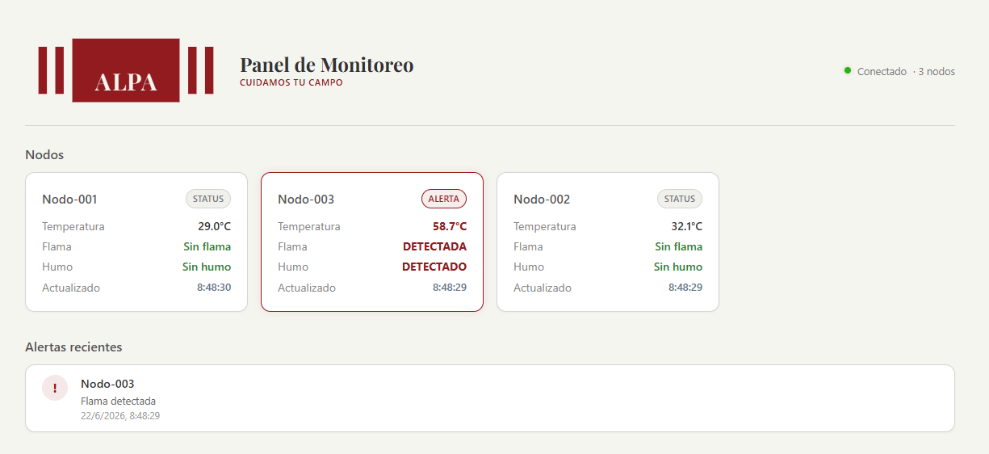
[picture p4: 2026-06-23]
Comunicacion/Assets/dash.png

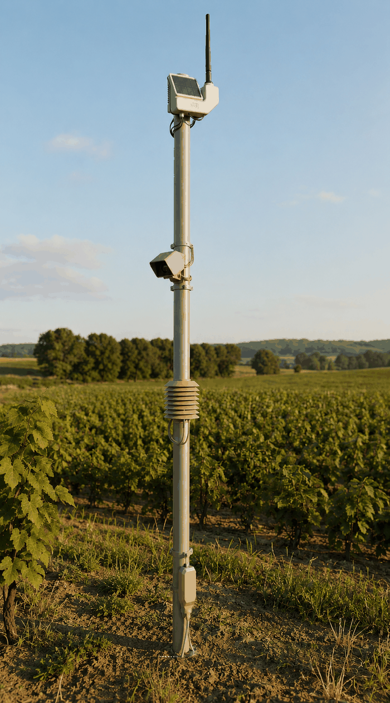
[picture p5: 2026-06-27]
Comunicacion/Assets/poste.png

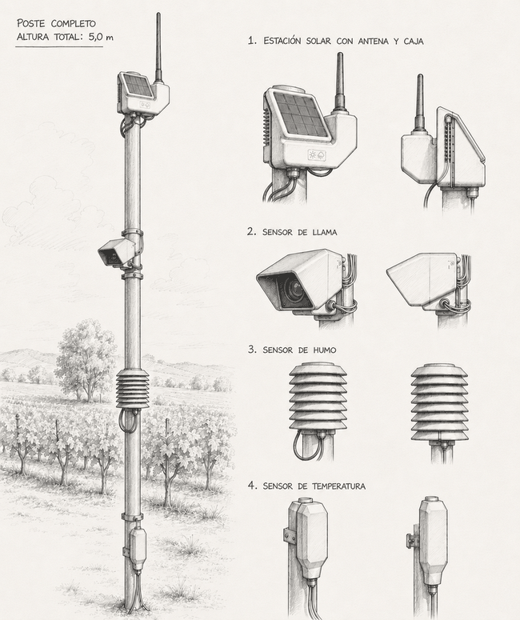
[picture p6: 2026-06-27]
Comunicacion/Assets/sketch.png

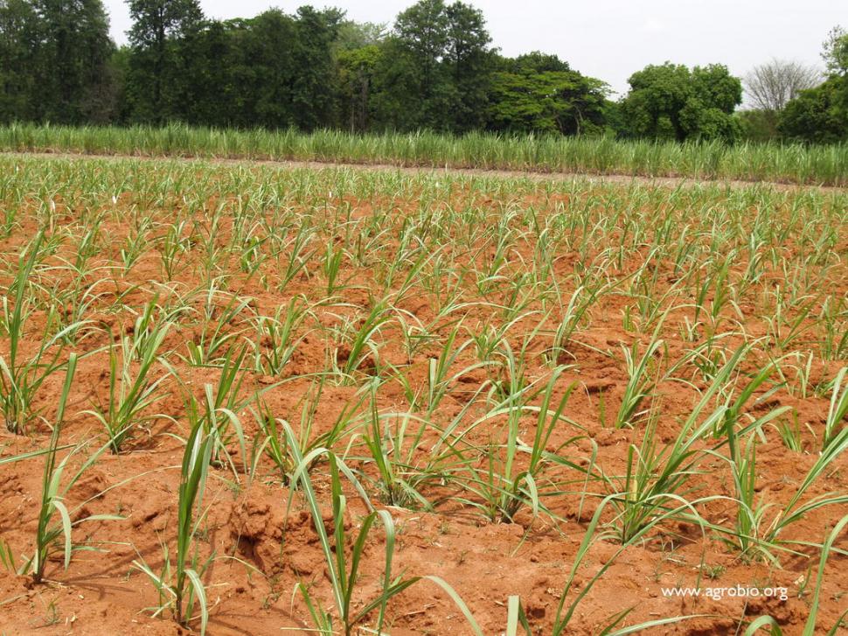
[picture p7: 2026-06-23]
Comunicacion/Assets/mood1.jpg

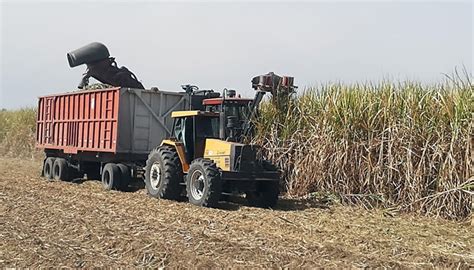
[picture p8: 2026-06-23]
Comunicacion/Assets/mood5.jpg

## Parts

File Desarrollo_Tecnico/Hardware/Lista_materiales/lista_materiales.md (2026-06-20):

# Inventario de Componentes

> **Actualizado:** 2026-06-10

## Placas de desarrollo

| Componente | Cantidad | Estado | Notas |
|---|---|---|---|
| WeMos LOLIN32 (ESP32 WROOM) | 1 | En mano | Prototipo 1 |
| Seeed XIAO ESP32-S3 | 2 | En mano | Prototipo 2 — nodo sensor + receptor |
| Wio-SX1262 (shield LoRa) | 2 | En mano | Shield para XIAO, 915 MHz |

## Sensores

| Componente | Cantidad | Estado | Notas |
|---|---|---|---|
| DS18B20 | 1 | En mano | Temperatura OneWire, ±0.5°C |
| KY-026 | 1 | En mano | Llama, salida digital + analógica |
| Alarma humo Geneve 79.06.01 | 1 | En mano | Sensor humo + buzzer 85dB integrado |
| GP2Y1014AU0F | 1 | En mano | Sensor óptico de polvo/humo por IR |

## Alimentación

| Componente | Cantidad | Estado | Notas |
|---|---|---|---|
| Portapilas 18650 | 2 | En mano | Para nodo sensor y receptor |
| Pila 18650 | 2 | En mano | Recargable |
| TP4056 | 2 | En mano | Cargador/protector LiPo con carga USB |

## Pasivos

| Componente | Valor | Cantidad | Estado | Para qué |
|---|---|---|---|---|
| Resistencia | 220 Ω (¼W) | 4 | En mano | LED indicador |
| Resistencia | 4.7 kΩ (¼W) | 2 | En mano | Pull-up DS18B20 |
| Resistencia | 150 Ω (¼W) | 2 | En mano | LED interno GP2Y1014 |
| Resistencia | 10 kΩ (¼W) | 2 | En mano | Pull-up salida GP2Y1014 |
| Capacitor electrolítico | 220 µF 16V | 2 | En mano | Estabilización GP2Y1014 |
| LED 5mm | — | 4 | En mano | Indicadores de estado |

## Conectividad y otros

| Componente | Cantidad | Estado | Notas |
|---|---|---|---|
| Protoboard | 1 | En mano | Para prototipado |
| Cables dupont M-M | ~20 | En mano | |
| Cable USB micro | 1 | En mano | WeMos / XIAO |
| Cable USB-C | 1 | En mano | XIAO |
| Buzzer activo 5V | 2 | En mano | Alarma audible |

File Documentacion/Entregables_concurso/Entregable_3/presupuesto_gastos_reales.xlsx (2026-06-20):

PRESUPUESTO DE INVERSIÓN INICIAL — PROTOTIPO FUNCIONAL
Equipo N.T. — Sistema de Alerta de Incendios Rurales
Problema: Incendios rurales en zonas sin conectividad - deteccion tardia (>30 min) |  |  | Solucion: Sistema IoT autonomo (ESP32 + LoRa) - alerta en <5 min sin celular ni red electrica
ITEM | CANTIDAD | MONTO x unidad | TOTAL del item | Mes/Inversion | Uso / Fuente de financiamiento
EQUIPAMIENTOS
Soldador de estanyo + estanyo + flux + pinzas + cinta aislante | 1 | 15000 | 15000 | Mes 1 | Herramientas de ensamblaje y soldadura - Recursos propios
Portatiles para desarrollo (ya disponibles) | 3 | 0 | 0 | Mes 1 | Desarrollo de software y firmware - Sin costo (ya se poseen)
TOTAL EQUIPAMIENTOS |  |  | 15000
MATERIALES (Componentes para prototipo)
Protoboard 400 pts | 2 | 4000 | 8000 | Mes 1 | Prototipado y pruebas de circuitos sin soldar - Recursos propios
Sensor de particulas/polvo GP2Y1014AU0F | 1 | 18000 | 18000 | Mes 1 | Deteccion de particulas de humo en nodo sensor - Recursos propios
Kit Seeed Studio XIAO ESP32S3 + LoRa Wio-SX1262 | 2 | 33000 | 66000 | Mes 1 | Microcontrolador + comunicacion LoRa nodos y gateway - Recursos propios
Combo cargador TP4056 USB-C + portapila 18650 | 2 | 5500 | 11000 | Mes 1 | Carga y alojamiento de baterias para alimentacion autonoma - Recursos propios
Sensor de llama / flama KY026 | 2 | 3600 | 7200 | Mes 1 | Deteccion de radiacion infrarroja de llama - Recursos propios
Pack 40 cables dupont hembra-hembra 20cm | 3 | 3000 | 9000 | Mes 1 | Conexiones electricas para prototipado en protoboard - Recursos propios
Pila recargable 18650 Motoma 3000mAh 3.7V | 2 | 17200 | 34400 | Mes 1 | Alimentacion recargable para nodos sensores - Recursos propios
TOTAL MATERIALES |  |  | 153600
DESARROLLO
Desarrollo de firmware ESP32 (nodos sensores + gateway) | 0 | 0 | 0 | Mes 1-2 | Realizado por el equipo - Sin costo externo. Valor mercado: ~$1,500,000 ARS
Desarrollo de backend API + dashboard web | 0 | 0 | 0 | Mes 1-2 | Realizado por el equipo - Sin costo externo. Valor mercado: ~$2,000,000 ARS
Impresion 3D de carcasas (bootcamp presencial 3/7) | 0 | 0 | 0 | Mes 2 | Pendiente - A definir en bootcamp presencial 3/7
TOTAL DESARROLLO |  |  | 0
INFRAESTRUCTURA
Hosting y servidor cloud | 0 | 0 | 0 | Mes 1-3 | Uso de recursos propios - Sin costo. A futuro: servidor cloud ~$15,000/mes ARS
Registro de dominio | 0 | 0 | 0 | - | Pendiente. A futuro: ~$10,000/anual ARS (ej. .com.ar)
TOTAL INFRAESTRUCTURA |  |  | 0
TOTAL GENERAL DEL PROYECTO (ARS) |  |  | 168600
Nota: Costos expresados en ARS (Pesos Argentinos). Desarrollo e infraestructura realizados por el equipo sin costo externo (bootstrapping). Valores de mercado estimados incluidos como referencia. Impresion 3D de carcasas diferida al bootcamp presencial del 3 de julio. A futuro: servidor cloud ~$15,000/mes + dominio ~$10,000/anual.

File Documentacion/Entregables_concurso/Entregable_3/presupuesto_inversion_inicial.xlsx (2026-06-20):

INVERSION INICIAL REQUERIDA - LANZAMIENTO PROTOTIPO FUNCIONAL
Equipo N.T. - Sistema de Alerta de Incendios Rurales
Problema: Incendios rurales en zonas sin conectividad - deteccion tardia (>30 min) |  |  | Solucion: Sistema IoT autonomo (ESP32 + LoRa) - alerta en <5 min sin celular ni red electrica
ITEM | CANT. | PRECIO UNIT. | TOTAL | Mes/Inversion | Uso / Fuente
1. EQUIPAMIENTOS (Herramientas de taller)
Soldador de estanyo + estanyo + flux + pinzas + cinta | 1 | 15000 | 15000 | Mes 1 | Ensamblaje y soldadura - Recursos propios
Portatiles para desarrollo (ya disponibles) | 3 | 0 | 0 | Mes 1 | Desarrollo - Sin costo (ya se poseen)
TOTAL EQUIPAMIENTOS |  |  | 15000
2. GATEWAY (Receptor central - 1 por kit)
Seeed Studio XIAO ESP32-S3 + Wio-SX1262 LoRa | 1 | 33000 | 33000 | Mes 1 | Microcontrolador + modulo LoRa para recepcion
Combo TP4056 USB-C + portapila 18650 | 1 | 5500 | 5500 | Mes 1 | Carga y alojamiento de bateria
Pila recargable 18650 Motoma 3000mAh 3.7V | 1 | 17200 | 17200 | Mes 1 | Alimentacion autonoma del gateway
Buzzer activo 5V | 1 | 1500 | 1500 | Mes 1 | Alarma sonora local en gateway
LED 5mm + resistencia 220R | 2 | 500 | 1000 | Mes 1 | Indicador visual de alerta
Cables dupont y conectores | 1 | 3000 | 3000 | Mes 1 | Conexiones internas del gateway
TOTAL GATEWAY (1 unidad) |  |  | 62200
3. NODO SENSOR (Modulo de deteccion - 1 por nodo)
Seeed Studio XIAO ESP32-S3 + Wio-SX1262 LoRa | 1 | 33000 | 33000 | Mes 1 | Microcontrolador + modulo LoRa para transmision
Sensor de particulas/polvo GP2Y1014AU0F | 1 | 18000 | 18000 | Mes 1 | Deteccion de humo/particulas de combustion
Sensor de llama KY026 | 1 | 3600 | 3600 | Mes 1 | Deteccion de radiacion infrarroja de llama
Sensor de temperatura DS18B20 | 1 | 3500 | 3500 | Mes 1 | Deteccion de picos de temperatura
Combo TP4056 USB-C + portapila 18650 | 1 | 5500 | 5500 | Mes 1 | Carga y alojamiento de bateria
Pila recargable 18650 Motoma 3000mAh 3.7V | 1 | 17200 | 17200 | Mes 1 | Alimentacion autonoma del nodo
Buzzer activo 5V | 1 | 1500 | 1500 | Mes 1 | Alarma sonora local en nodo
LED 5mm + resistencia 220R | 2 | 500 | 1000 | Mes 1 | Indicador visual de estado
Resistencias, capacitor 220uF y componentes | 1 | 5000 | 5000 | Mes 1 | Pull-up DS18B20, filtro GP2Y1014, etc.
TOTAL NODO SENSOR (1 unidad) |  |  | 89300
4. COMPARTIDOS Y TEST
Protoboard 400 pts (test y desarrollo) | 2 | 4000 | 8000 | Mes 1 | Prototipado y pruebas de circuitos
Pack cables dupont HH 20cm x40 (extra) | 2 | 3000 | 6000 | Mes 1 | Conexiones adicionales para prototipado
Cable USB-C para programacion | 2 | 2500 | 5000 | Mes 1 | Programacion y debug de XIAO ESP32-S3
TOTAL COMPARTIDOS |  |  | 38000
5. TOTAL PROTOTIPO (1 Gateway + 1 Nodo Sensor)
Total equipamiento + 1 gateway + 1 nodo + compartidos | 1 | 204500 | 204500 | Mes 1-2
SUBTOTAL PROTOTIPO (1 Gateway + 1 Nodo) |  |  | 204500
6. DESARROLLO E INFRAESTRUCTURA
Firmware ESP32 (nodos + gateway) | 0 | 0 | 0 | Mes 1-2 | Realizado por el equipo - Sin costo. Valor mercado: ~$1.500.000
Backend API + Dashboard web | 0 | 0 | 0 | Mes 1-2 | Realizado por el equipo - Sin costo. Valor mercado: ~$2.000.000
Diseno de PCB definitivo (KiCad) | 0 | 0 | 0 | Mes 2 | Realizado por el equipo - Sin costo. Valor mercado: ~$300.000
Impresion 3D de carcasas profesionales | 4 | 15000 | 60000 | Mes 2 | Servicio externo: 2 carcasas nodo + 1 gateway + 1 respaldo
Servidor cloud VPS (3 meses) | 1 | 45000 | 45000 | Mes 1-3 | Hosting backend + dashboard ($15.000/mes x 3)
Registro de dominio .com.ar (1 año) | 1 | 10000 | 10000 | Mes 1 | Dominio web
TOTAL DESARROLLO E INFRAESTRUCTURA |  |  | 115000
7. CONTINGENCIA (10%)
Imprevistos, reemplazo de componentes y envios | 1 | 31950 | 31950 | Mes 1-2 | Margen de seguridad del 10% sobre el total
TOTAL CONTINGENCIA |  |  | 31950
INVERSION TOTAL REQUERIDA (ARS) |  |  | 351450
RESUMEN DE COSTOS UNITARIOS
Costo unitario GATEWAY (1 unidad) | 1 | 62200 | 62200 | - | Componentes electronicos + bateria
Costo unitario NODO SENSOR (1 unidad) | 1 | 89300 | 89300 | - | Componentes electronicos + sensores + bateria
Costo prototipo completo (1 Gateway + 1 Nodo) | 1 | 204500 | 204500 | - | Equipamiento + gateway + nodo + compartidos
Nota: Esta planilla refleja la inversion total necesaria para lanzar un prototipo funcional. El desarrollo de firmware, backend y diseno PCB es realizado por el equipo sin costo externo (valor de mercado estimado: ~$3.800.000 ARS). Para un kit de produccion tipico (1 Gateway + N nodos sensores), multiplicar el costo del nodo por N. Ver desglose de gastos reales en: presupuesto_gastos_reales.xlsx

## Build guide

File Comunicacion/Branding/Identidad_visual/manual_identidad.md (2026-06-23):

# Manual de Identidad Visual — ALPA

---

## Descripción general

El isologotipo es una composición geométrica y simétrica. Está formado por un rectángulo central sólido en color rojo oscuro (`#911B1E`), flanqueado a ambos lados por dos pares de barras verticales paralelas del mismo color. Dentro del bloque central se ubica la palabra **ALPA** calada (*negative space*), cuyo color depende del fondo sobre el que se muestre, generada con la tipografía **Playfair Display** en peso **700 (bold)** y tamaño **70px**, con espaciado ajustado entre letras (`A–L: -11`, `L–P: -12`, `P–A: -15`).

---

## Significado de los elementos

### Bloque central

Actúa como el núcleo de la marca. Visualmente representa la caja del hardware (el nodo sensor o el gateway), transmitiendo robustez, estabilidad y contención.

### Barras laterales

Su disposición vertical a los lados del bloque tiene un triple significado conceptual:

- **Conectividad:** Simulan gráficamente la propagación de las ondas de señal inalámbrica (LoRa y WiFi) emitidas por el nodo central.
- **Entorno rural:** Evocan la imagen de los postes y alambrados que marcan los límites en el campo.
- **Identidad local:** Representan las franjas características del poncho tucumano, simbolizando el arraigo regional, la cultura local y el concepto de "protección" o cobertura.

### Color rojo oscuro (`#911B1E`)

Cumple una doble función:

1. Por un lado, es el color universal de la alerta, el calor y el fuego (la amenaza que el sistema combate).
2. Por otro lado, remite al color natural de la tierra arcillosa (*Allpa*, en quechua) y al tinte tradicional de los telares norteños.

### Tagline: "Cuidamos tu campo"

Refleja el compromiso directo con el productor. Tono protector, cercano y regional.

---

## Paleta de colores

| Color | Código | Uso |
|---|---|---|
| **Rojo inca** (primario) | `#911B1E` | Logo, acentos, headers, alertas, CTA |
| **Pizarra** | `#222222` | Fondos oscuros, texto principal en contraste claro |
| **Lino crudo** (secundario) | `#D4B896` | Fondos de presentaciones, detalles, slide de cierre |
| **Hueso** | `#F5F5F5` | Fondo de dashboard, impresos, tarjetas |

---

## Tipografía

| Rol | Fuente | Peso |
|---|---|---|
| **Logo** | Playfair Display | 700 (bold) |
| **Títulos** | Playfair Display | 700 (bold) |
| **Cuerpo / UI** | Montserrat | 300 (light), 400 (regular), 700 (bold) |

- **Playfair Display** (serif) se usa para títulos, cabeceras y el logo. Comunica institucionalidad, tradición y confianza.
- **Montserrat** (sans-serif) se usa para todo texto de cuerpo, etiquetas, leyendas y elementos de UI. Limpia, legible y moderna.

---

## Estilo general

- **Dashboard:** Tema claro. Fondo `#F5F5F5` (hueso), cards blancas, bordes sutiles. Acentos en `#911B1E` (rojo inca).
- **Presentaciones / slides:** Fondo oscuro `#222222` (pizarra) o lino crudo `#D4B896` según el slide. Logo en versión blanca sobre oscuro, o roja sobre claro.
- **Impresos (one pager, flyers):** Fondo hueso o blanco, acentos rojo inca. Máximo una carilla.

---

## Uso del logo

- **Sobre fondo hueso/blanco:** Logo estándar (barras rojas + bloque rojo con texto calado en blanco).
- **Sobre fondo rojo inca:** Logo invertido (barras y bloque en blanco, texto calado sobre blanco).
- **Sobre fondo pizarra:** Logo en blanco.
- **Sobre fondo lino crudo:** Logo estándar (barras rojas, texto calado sobre lino crudo).
- **Tamaño mínimo:** 36 px de ancho en pantalla. No reducir más.
- **Área de resguardo:** Espacio libre igual al ancho de una barra vertical a cada lado.

---

## Tono de voz

- Cercano, protector, regional.
- Frases cortas. Vocabulario simple.
- El productor es "el que cuida el campo", ALPA lo ayuda a cuidarlo.

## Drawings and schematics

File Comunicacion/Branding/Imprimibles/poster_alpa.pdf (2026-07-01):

## Sistema de Alerta de Incendios Rurales

Por eso creamos...

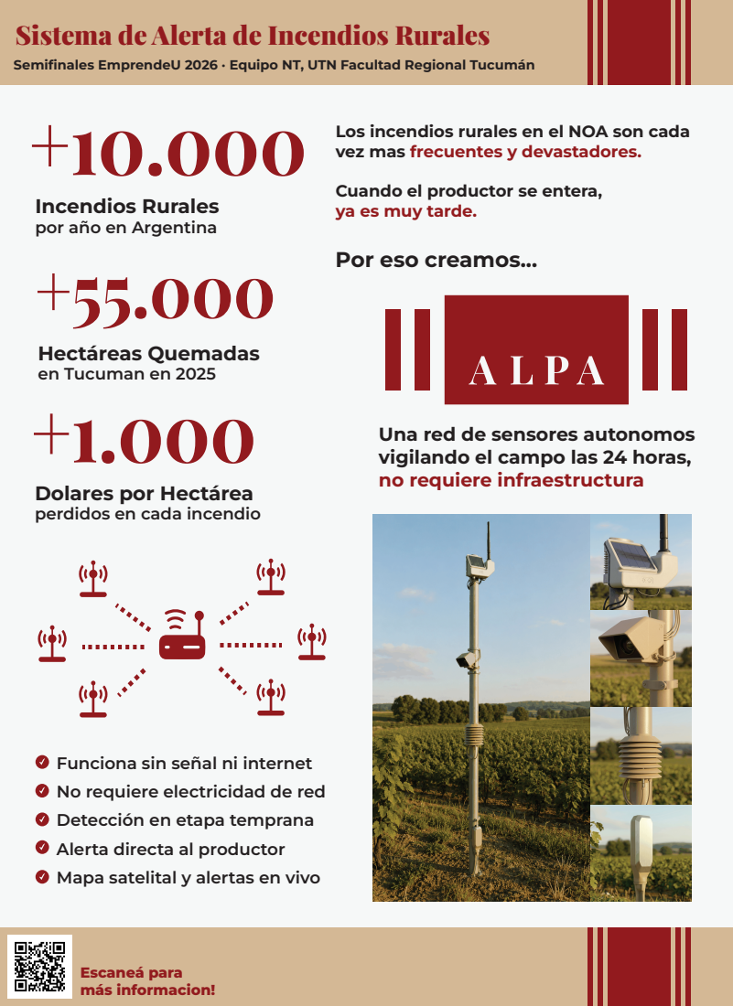
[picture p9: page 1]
Escaneá para más informacion!

Semifinales EmprendeU 2026 · Equipo NT, UTN Facultad Regional Tucumán

Los incendios rurales en el NOA son cada
vez mas frecuentes y devastadores.
Cuando el productor se entera,
ya es muy tarde.

Incendios Rurales
por año en Argentina

Hectáreas Quemadas
en Tucuman en 2025

Una red de sensores autonomos
vigilando el campo las 24 horas,
no requiere infraestructura

Dolares por Hectárea
perdidos en cada incendio

Funciona sin señal ni internet
No requiere electricidad de red
Detección en etapa temprana
Alerta directa al productor
Mapa satelital y alertas en vivo

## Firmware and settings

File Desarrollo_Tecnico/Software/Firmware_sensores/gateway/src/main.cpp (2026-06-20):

/*
 * ESP32 Gateway — XIAO S3 + WIO-SX1262 (LoRa + WiFi)
 *
 * Placa: Seeed Studio XIAO ESP32S3 + Wio-SX1262 (conector B2B)
 * Pines SX1262 via B2B: NSS=41, DIO1=39, RST=42, BUSY=40, ANT_SW=38
 * SPI: SCK=7, MISO=8, MOSI=9
 *
 * Recibe un struct binario de 11 bytes del Nodo por LoRa
 * y lo envía como JSON al servidor por HTTP (WiFi).
 *
 * HTTP POST a http://<API_HOST>:<API_PORT>/api/eventos
 * Body: {"nodo":"nodo-xiao_01","temperatura":25.31,"flama":0,"humo":0,"tipo":"status"}
 */

#include <Arduino.h>
#include <WiFi.h>
#include <HTTPClient.h>
#include <RadioLib.h>
#include <ArduinoJson.h>

// --- WiFi ---
#define WIFI_SSID     "NODO"
#define WIFI_PASS     "12345678"

// --- Servidor API ---
#define API_HOST      "172.28.56.101"
#define API_PORT      3001
#define API_ENDPOINT  "/api/eventos"

// --- Configuración LoRa (B2B connector - XIAO ESP32S3 + Wio-SX1262 Kit) ---
#define LORA_CS     41    // NSS
#define LORA_DIO1   39    // IRQ
#define LORA_RST    42    // Reset
#define LORA_BUSY   40    // Busy
#define LORA_ANT_SW 38    // Antenna switch (DIO2)
#define LORA_PWR_EN 5     // Power enable para SX1262

#define LORA_SCK    7
#define LORA_MISO   8
#define LORA_MOSI   9

#define LORA_FREQ    915.0
#define LORA_SF      7
#define LORA_BW      125.0
#define LORA_CR      5
#define LORA_SYNC    0x12
#define LORA_POWER   22

// --- Mapeo nodeId uint8_t → string ---
const char* MAPA_NODOS[] = {
  "nodo-xiao_01", "nodo-xiao_02", "nodo-xiao_03", "nodo-xiao_04"
};
const int CANT_NODOS = 4;

// --- Struct del paquete LoRa (11 bytes) ---
struct __attribute__((packed)) Packet {
  uint8_t  nodeId;
  uint32_t uptime;
  float    temperatura;
  uint8_t  flama;
  uint8_t  humo;
};

// --- Modo simulación ---
#define MODO_SIMULACION  false

// --- Variables ISR-safe para recepción LoRa ---
volatile bool loraReceived = false;

// --- Forward declarations ---
void procesarPaquete(uint8_t* buf, size_t len, float rssi, float snr);
bool clasificarAlerta(float temp, bool humo, bool flama);
void enviarAlServidor(const char* nodoId, float temp, bool flama, bool humo, const char* tipo);
void onLoRaReceive();
void initRadio();
#if MODO_SIMULACION
  void generarSimulacion();
#endif

SX1262 radio = new Module(LORA_CS, LORA_DIO1, LORA_RST, LORA_BUSY);

#if MODO_SIMULACION
  unsigned long ultimoSimul = 0;
  int cicloSimul = 0;
#endif

// ============================================================

void setup() {
  Serial.begin(115200);
  delay(1000);

  Serial.println(F("[GW] Iniciando Gateway XIAO S3 + SX1262 (B2B)..."));

  // Power enable para SX1262
  pinMode(LORA_PWR_EN, OUTPUT);
  digitalWrite(LORA_PWR_EN, HIGH);
  delay(100);

  // SPI explícito con pines correctos
  SPI.begin(LORA_SCK, LORA_MISO, LORA_MOSI, LORA_CS);

  // Reset manual del SX1262
  pinMode(LORA_RST, OUTPUT);
  digitalWrite(LORA_RST, LOW);
  delay(10);
  digitalWrite(LORA_RST, HIGH);
  delay(100);

  // Antenna switch (DIO2 como RF switch)
  pinMode(LORA_ANT_SW, OUTPUT);
  digitalWrite(LORA_ANT_SW, LOW);

  // WiFi
  Serial.print(F("[GW] Conectando a WiFi "));
  Serial.print(WIFI_SSID);
  WiFi.begin(WIFI_SSID, WIFI_PASS);
  int intentos = 0;
  while (WiFi.status() != WL_CONNECTED && intentos < 40) {
    delay(500);
    Serial.print(F("."));
    intentos++;
  }
  if (WiFi.status() == WL_CONNECTED) {
    Serial.println();
    Serial.print(F("[GW] WiFi conectado. IP: "));
    Serial.println(WiFi.localIP());
  } else {
    Serial.println();
    Serial.println(F("[GW] ERROR: no se pudo conectar WiFi"));
  }

  // LoRa
  initRadio();
}

// ============================================================

void initRadio() {
  Serial.println(F("[GW] Inicializando SX1262..."));

  int state = radio.begin(
    LORA_FREQ, LORA_BW, LORA_SF, LORA_CR,
    LORA_SYNC, LORA_POWER, 8, 1.6, false
  );

  if (state != RADIOLIB_ERR_NONE) {
    Serial.print(F("[GW] Error LoRa: "));
    Serial.println(state);
    if (state == RADIOLIB_ERR_CHIP_NOT_FOUND) {
      Serial.println(F("[GW] SX1262 no responde - revisar conexion B2B y alimentacion"));
    }
    return;
  }

  // Configurar antenna switch via DIO2
  radio.setDio2AsRfSwitch();

  Serial.println(F("[GW] SX1262 listo!"));
  radio.setDio1Action(onLoRaReceive);
  radio.startReceive();

#if MODO_SIMULACION
  Serial.println(F("[GW] MODO SIMULACION"));
#else
  Serial.println(F("[GW] Esperando paquetes LoRa..."));
#endif
}

// ============================================================

void loop() {
  if (loraReceived) {
    loraReceived = false;

    uint8_t buf[64];
    size_t len = sizeof(buf);
    int state = radio.readData(buf, len);

    if (state == RADIOLIB_ERR_NONE) {
      float rssi = radio.getRSSI();
      float snr = radio.getSNR();
      procesarPaquete(buf, len, rssi, snr);
    } else {
      Serial.print(F("[GW] Error lectura LoRa: "));
      Serial.println(state);
    }

    radio.startReceive();
  }

#if MODO_SIMULACION
  if (millis() - ultimoSimul > 4000) {
    ultimoSimul = millis();
    generarSimulacion();
  }
#endif
}

// ============================================================

void IRAM_ATTR onLoRaReceive() {
  loraReceived = true;
}

// ============================================================

void procesarPaquete(uint8_t* buf, size_t len, float rssi, float snr) {
  if (len < sizeof(Packet)) {
    Serial.print(F("[GW] Paquete demasiado corto: "));
    Serial.println(len);
    return;
  }

  Packet pkt;
  memcpy(&pkt, buf, sizeof(Packet));

  if (pkt.nodeId >= CANT_NODOS) {
    Serial.print(F("[GW] nodeId desconocido: "));
    Serial.println(pkt.nodeId);
    return;
  }

  const char* nodoId = MAPA_NODOS[pkt.nodeId];
  float temp = pkt.temperatura;
  bool flama = pkt.flama > 0;
  bool humo = pkt.humo > 0;
  unsigned long uptimeNodo = pkt.uptime;

  const char* tipo = clasificarAlerta(temp, humo, flama) ? "alerta" : "status";

  enviarAlServidor(nodoId, temp, flama, humo, tipo);

  Serial.print(F("[GW] LoRa <- "));
  Serial.print(nodoId);
  Serial.print(F(" | "));
  Serial.print(temp);
  Serial.print(F("C | flama="));
  Serial.print(flama);
  Serial.print(F(" humo="));
  Serial.print(humo);
  Serial.print(F(" | uptime_nodo="));
  Serial.print(uptimeNodo);
  Serial.print(F("s | "));
  Serial.print(tipo);
  Serial.print(F(" | RSSI: "));
  Serial.print(rssi);
  Serial.print(F(" dBm | SNR: "));
  Serial.print(snr);
  Serial.println(F(" dB"));
}

// ============================================================

bool clasificarAlerta(float temp, bool humo, bool flama) {
  if (flama) return true;
  if (temp > 50.0) return true;
  if (humo) return true;
  return false;
}

// ============================================================

void enviarAlServidor(const char* nodoId, float temp, bool flama, bool humo, const char* tipo) {
  if (WiFi.status() != WL_CONNECTED) {
    Serial.println(F("[GW] Sin WiFi, no se puede enviar"));
    return;
  }

  HTTPClient http;
  char url[64];
  snprintf(url, sizeof(url), "http://%s:%d%s", API_HOST, API_PORT, API_ENDPOINT);

  http.begin(url);
  http.addHeader("Content-Type", "application/json");

  JsonDocument doc;
  doc["nodo"] = nodoId;
  doc["temperatura"] = temp;
  doc["flama"] = flama ? 1 : 0;
  doc["humo"] = humo ? 1 : 0;
  doc["tipo"] = tipo;

  String body;
  serializeJson(doc, body);

  int codigo = http.POST(body);

  if (codigo > 0) {
    Serial.print(F("[GW] HTTP POST "));
    Serial.print(url);
    Serial.print(F(" -> "));
    Serial.println(codigo);
  } else {
    Serial.print(F("[GW] Error HTTP POST: "));
    Serial.println(http.errorToString(codigo));
  }

  http.end();
}

// ============================================================

void enviarSerial(const char* nodoId, float temp, bool flama, bool humo, const char* tipo) {
  JsonDocument doc;
  doc["nodo"] = nodoId;
  doc["temperatura"] = temp;
  doc["flama"] = flama ? 1 : 0;
  doc["humo"] = humo ? 1 : 0;
  doc["tipo"] = tipo;

  serializeJson(doc, Serial);
  Serial.println();
}

// ============================================================

#if MODO_SIMULACION
void generarSimulacion() {
  Packet pkt;
  pkt.nodeId = cicloSimul % CANT_NODOS;
  pkt.uptime = millis() / 1000;
  pkt.temperatura = 28.0 + random(0, 100) / 10.0;
  pkt.flama = random(0, 100) < 4;
  pkt.humo = random(0, 100) < 10;

  bool esAlerta = random(0, 100) < 8;
  if (esAlerta) {
    pkt.temperatura = 48.0 + random(0, 80) / 10.0;
    pkt.flama = 1;
    pkt.humo = 1;
  }

  const char* nodoId = MAPA_NODOS[pkt.nodeId];
  float temp = pkt.temperatura;
  bool flama = pkt.flama > 0;
  bool humo = pkt.humo > 0;
  const char* tipo = esAlerta ? "alerta" : "status";

  enviarAlServidor(nodoId, temp, flama, humo, tipo);

  Serial.print(F("[GW] Simul <- "));
  Serial.print(nodoId);
  Serial.print(F(" | "));
  Serial.print(temp);
  Serial.print(F("C | flama="));
  Serial.print(flama);
  Serial.print(F(" humo="));
  Serial.print(humo);
  Serial.print(F(" | uptime="));
  Serial.print(pkt.uptime);
  Serial.print(F("s | "));
  Serial.println(tipo);

  cicloSimul++;
}
#endif

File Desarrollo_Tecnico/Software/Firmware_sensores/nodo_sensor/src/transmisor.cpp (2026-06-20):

#include <Arduino.h>
#include <OneWire.h>
#include <DallasTemperature.h>
#include <RadioLib.h>

#define PIN_DS18B20  3
#define PIN_KY026    4
#define PIN_HUMO_A   6
#define PIN_HUMO_B   2
#define NODE_ID      "nodo_xiao_01_fixed"
#define NODE_ID_NUM  0

#define LORA_CS     41
#define LORA_DIO1   39
#define LORA_RST    42
#define LORA_BUSY   40
#define LORA_ANT_SW 38
#define LORA_PWR_EN 5

#define LORA_SCK    7
#define LORA_MISO   8
#define LORA_MOSI   9

#define LORA_FREQ    915.0
#define LORA_SF      7
#define LORA_BW      125.0
#define LORA_CR      5
#define LORA_SYNC    0x12
#define LORA_POWER   22

#define POLL_MS      20
#define REPORTE_MS   5000
#define TIEMPO_CONV  750

struct __attribute__((packed)) Packet {
    uint8_t  nodeId;
    uint32_t uptime;
    float    temperatura;
    uint8_t  flama;
    uint8_t  humo;
};

OneWire oneWire(PIN_DS18B20);
DallasTemperature sensors(&oneWire);
SX1262 radio = new Module(LORA_CS, LORA_DIO1, LORA_RST, LORA_BUSY);

bool flamaFlag = false;
bool humoFlag = false;
float temperatura = DEVICE_DISCONNECTED_C;
unsigned long ultimoRequest = 0;

void initRadio() {
    pinMode(LORA_PWR_EN, OUTPUT);
    digitalWrite(LORA_PWR_EN, HIGH);
    delay(100);

    SPI.begin(LORA_SCK, LORA_MISO, LORA_MOSI, LORA_CS);

    pinMode(LORA_RST, OUTPUT);
    digitalWrite(LORA_RST, LOW);
    delay(10);
    digitalWrite(LORA_RST, HIGH);
    delay(100);

    pinMode(LORA_ANT_SW, OUTPUT);
    digitalWrite(LORA_ANT_SW, LOW);

    int state = radio.begin(LORA_FREQ, LORA_BW, LORA_SF, LORA_CR,
                            LORA_SYNC, LORA_POWER, 8, 1.6, false);

    Serial.print("{\"nodo\":\"" NODE_ID "\",\"lora_err\":");
    Serial.print(state);
    if (state == RADIOLIB_ERR_NONE) {
        radio.setDio2AsRfSwitch();
        Serial.println(",\"lora\":\"ok\"}");
    } else {
        Serial.println("}");
    }
}

void setup() {
    Serial.begin(115200);
    pinMode(PIN_KY026, INPUT_PULLUP);
    pinMode(PIN_HUMO_A, INPUT_PULLUP);
    pinMode(PIN_HUMO_B, INPUT_PULLUP);
    sensors.begin();
    sensors.setWaitForConversion(false);
    delay(100);
    if (sensors.getDeviceCount() == 0)
        Serial.println("{\"nodo\":\"" NODE_ID "\",\"error\":\"DS18B20 no detectado\"}");

    sensors.requestTemperatures();
    ultimoRequest = millis();

    initRadio();
}

void loop() {
    static unsigned long tPoll = 0, tReporte = 0;

    unsigned long now = millis();

    if (now - tPoll >= POLL_MS) {
        tPoll = now;
        int flame = digitalRead(PIN_KY026);
        int humoA = digitalRead(PIN_HUMO_A);
        int humoB = digitalRead(PIN_HUMO_B);
        if (flame == HIGH) flamaFlag = true;
        if (humoA != humoB) humoFlag = true;
    }

    if (now - ultimoRequest >= TIEMPO_CONV) {
        float raw = sensors.getTempCByIndex(0);
        if (raw > -55.0 && raw < 125.0)
            temperatura = raw;
        sensors.requestTemperatures();
        ultimoRequest = now;
    }

    if (now - tReporte >= REPORTE_MS) {
        tReporte = now;

        int hA = digitalRead(PIN_HUMO_A);
        int hB = digitalRead(PIN_HUMO_B);

        Serial.print("{\"nodo\":\"");
        Serial.print(NODE_ID);
        Serial.print("\",\"uptime\":");
        Serial.print(now / 1000);
        Serial.print(",\"temperatura\":");
        Serial.print(temperatura, 2);
        Serial.print(",\"flama\":");
        Serial.print(flamaFlag ? 1 : 0);
        Serial.print(",\"humo\":");
        Serial.print(humoFlag ? 1 : 0);
        Serial.print(",\"hA\":");
        Serial.print(hA);
        Serial.print(",\"hB\":");
        Serial.print(hB);

        Packet pkt;
        pkt.nodeId = NODE_ID_NUM;
        pkt.uptime = now / 1000;
        pkt.temperatura = temperatura;
        pkt.flama = flamaFlag ? 1 : 0;
        pkt.humo = humoFlag ? 1 : 0;

        int loraState = radio.transmit((uint8_t*)&pkt, sizeof(pkt));
        Serial.print(",\"lora_tx\":");
        Serial.print(loraState);
        Serial.println("}");

        flamaFlag = false;
        humoFlag = false;
    }
}

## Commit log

2026-06-20 Initial commit: sistema de alerta de incendios rurales
    [presupuesto_gastos_reales.xlsx, presupuesto_inversion_inicial.xlsx]
2026-06-26 feat: integra documentos de Mario en Documentacion/ y corrige cifra de establecimientos (35k→15k)
2026-06-26 feat: agrega informe de auditoría de Documentacion/ (this-work-is-shit)
2026-06-26 fix: corrige hallazgos de auditoría (temas obsoletos, naming, inventario)
2026-06-26 fix: renombra Desarrollo_tecnico → Desarrollo_Tecnico (mayúscula)
    [main.cpp, transmisor.cpp]
2026-06-26 audit: reportes this-work-is-shit para comunicacion, desarrollo-tecnico y documentacion
2026-06-27 audit: cifras y contenido en 32 archivos .md — 12 inconsistencias detectadas
2026-06-27 fix: resolver 8 inconsistencias de cifras y contenido auditoria
2026-06-27 docs: aclarar que limite de 4 nodos es de implementacion, no teorico; escalabilidad hasta 50 nodos
2026-06-27 feat: merge Dashboard de feature/login-demo — login, mapa Leaflet, simulación, modo demo
2026-06-27 chore: limpiar scratch/ de develop (auditorías internas)
2026-07-01 scratch: traidos archivos de main a develop
2026-07-01 imprimibles: traidos de main a develop
